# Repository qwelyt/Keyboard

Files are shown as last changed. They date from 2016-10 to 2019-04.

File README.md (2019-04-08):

# Keyboard
I'm building my own keyboard.
It's as simple as that.

Why? Because I want to. And I've yet to find a keyboard that looks the way I want it to. The solution seems to be to build your own. So that's what I'm doing.

## Layout
The layout is a split keyboard with the keys in a matrix. Here's a pic (v2)
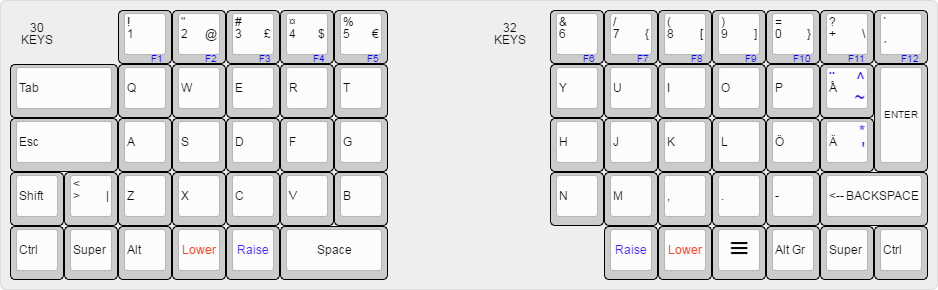
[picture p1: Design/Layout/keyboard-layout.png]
layout


### Why split?
Every keyboard I've tried have always forced you to put your hands inwards, in a / \ way (pretend that's your arms). But I want to be able to keep my arms like | | or even \ /. With a split keyboard where you can move each module to where you want it to be you can achive this. I *think* this would give you better ergonomics, but we'll see. We might be using the one-module-fits-all approach for more than just cheaper-to-produce reasons. But if you never try, you never know.

### Why a linear matrix layout?
As far as I've found, the only reason we use keyboards with slanted columns is because 'it has always been like that'. Like, from the typewriter-era. And then it was for mechanical reasons. But now that we no longer have metal arms that must be physically fit into the layout, we can design it just as we want. And apparently the slanted-columns-layout is bad for you. You stretch your fingers in an un-natural way which puts strain on your limbs and increases the odds of injury.
That is just bad. So I'm going for a linear matrix layout because I like my fingers. They should have the best typing experiance they can have.

### Raise and Lower?
Do you really use *F1* so much that it needs its own dedicated key? I don't. So tucking it away under *Raise*+*1* works well. I think. Also, doing it layered gives you way more keys than you actually have. Take module A. It has 30 keys. 2 of which are layer modifiers. This gives me 28 keys to play with, in three layers. So I actually got 28x3 keys, so thats 84 keys in total. I probably won't use that many, but it is nice to have the possibility. Mainly though, it cuts down on parts used and size, which is a big things given that 3D-printers (or at least mine) can't print super-mega-big things. 
Credit where it is due: The Planck keyboard has this (https://youtu.be/bEPg8kk84gw) which influenced me to have it as well.

## Parts
This build is my first keyboard that I'm building from scratch. I've done a few mods, but never a complete build.
To build this I'm using some mechanical switches (Black ALPS) that I 'rescued' from a to-be-thrown Dell AT101. I've got 104 keys from that old keyboard. Most of which still have the click sound. And I have the caps, ofc.

The modules cases is made to be 3D printed. I use a FlashForge Finder to print.

It's NKRO, so there is an 1N4149 diode for every switch.

The controller is an Arduino Micro (https://store.arduino.cc/arduino-micro).

Each module will be it's own keyboard. Meaning, each module will has it's own controller. So you don't need to plug in A to be able to use B and vice versa. This ofc means that, for 2 modules, you need 2 USB ports. One could build a USB hub as well to plug the modules into. Makes for a cleaner setup as you will only need 1 cable going to the computer. Might try building in retractable cables in everything if I take a stab at it, but well see how much of a pain that is.

# Log
| Todo | Doing | Done |
|---|---|---|
||| Create basic working matrix |
||| Create 3D sketches for modules |
|||Create schematics for matrix |
|||Get hands on a 3D printer|
||| Get diods |
||| Print test module |
||| Assemble test module |
||| Code test module |
||| Get real controller board |
||| Refactor |
||| Print module A |
||| Print module B |
||| Assemble A |
||| Assemble B |
||| Code A |
||| Code B |
|| ??? || 
| Refactor|||
| Profit|||

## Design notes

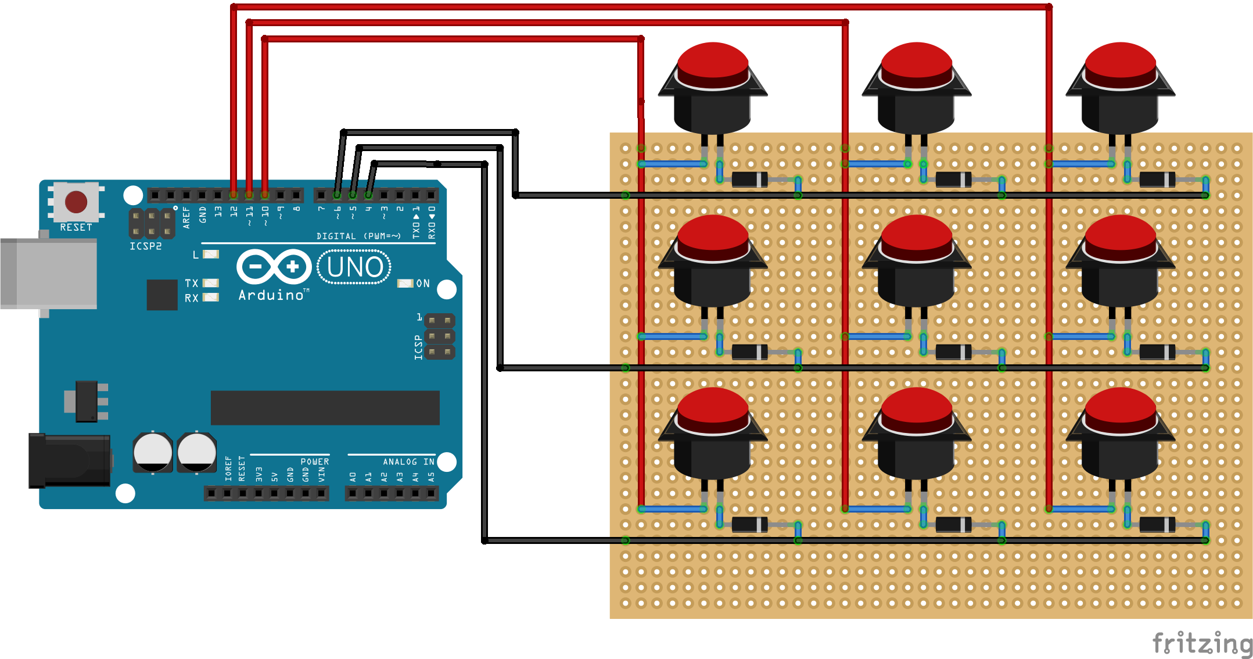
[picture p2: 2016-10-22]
Design/Schematics/matrix/matrix_bb.png

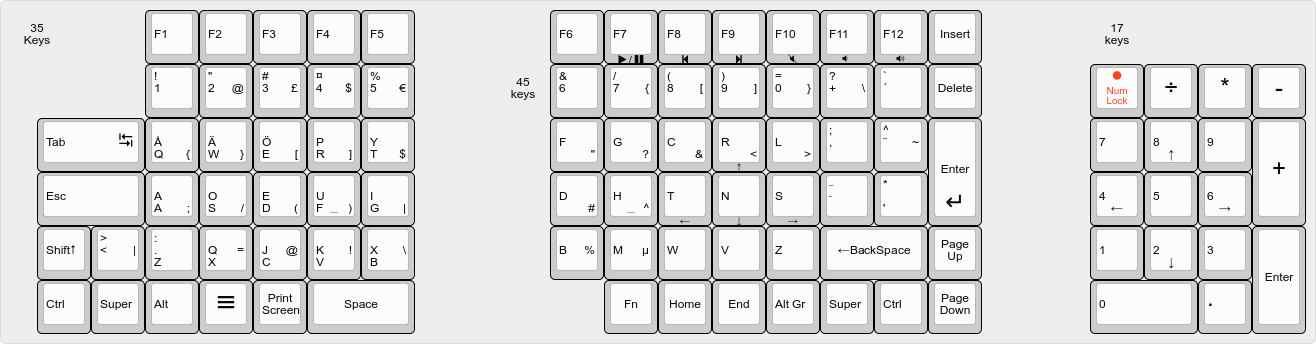
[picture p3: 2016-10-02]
Design/Layout/layout.png

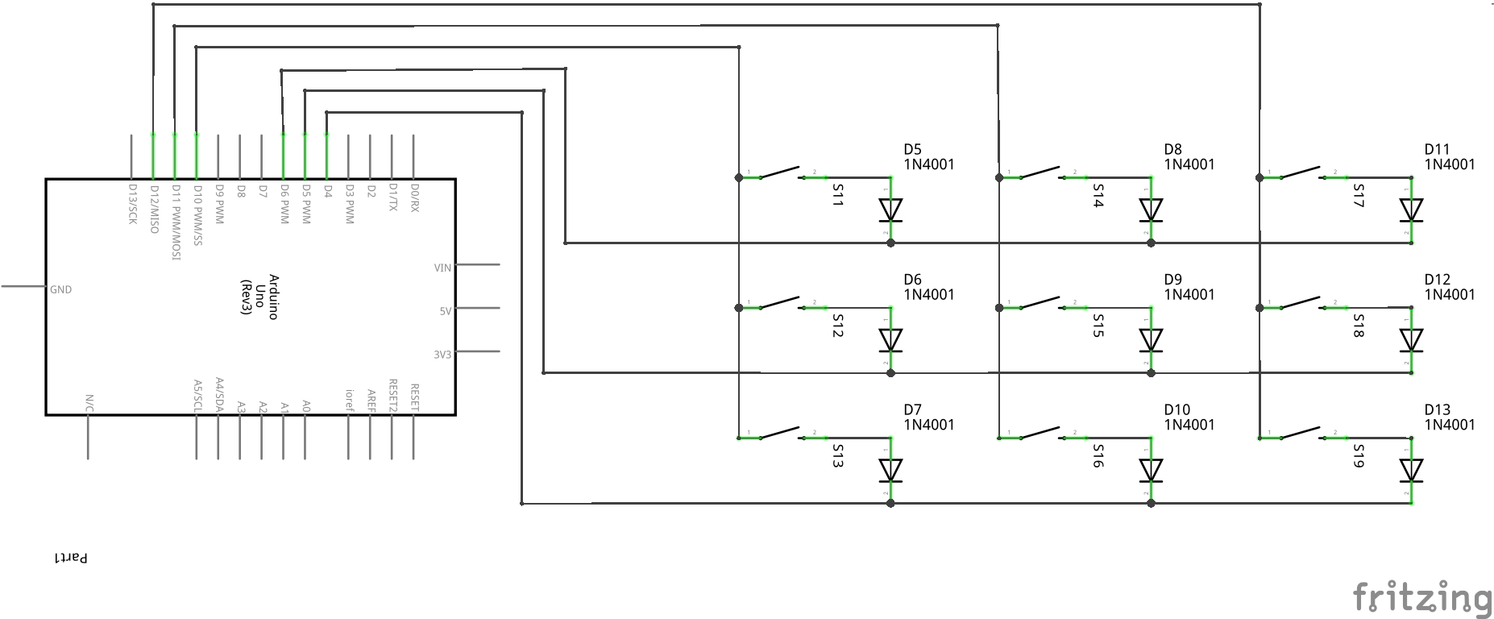
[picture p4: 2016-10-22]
Design/Schematics/matrix/matrix_schem.png

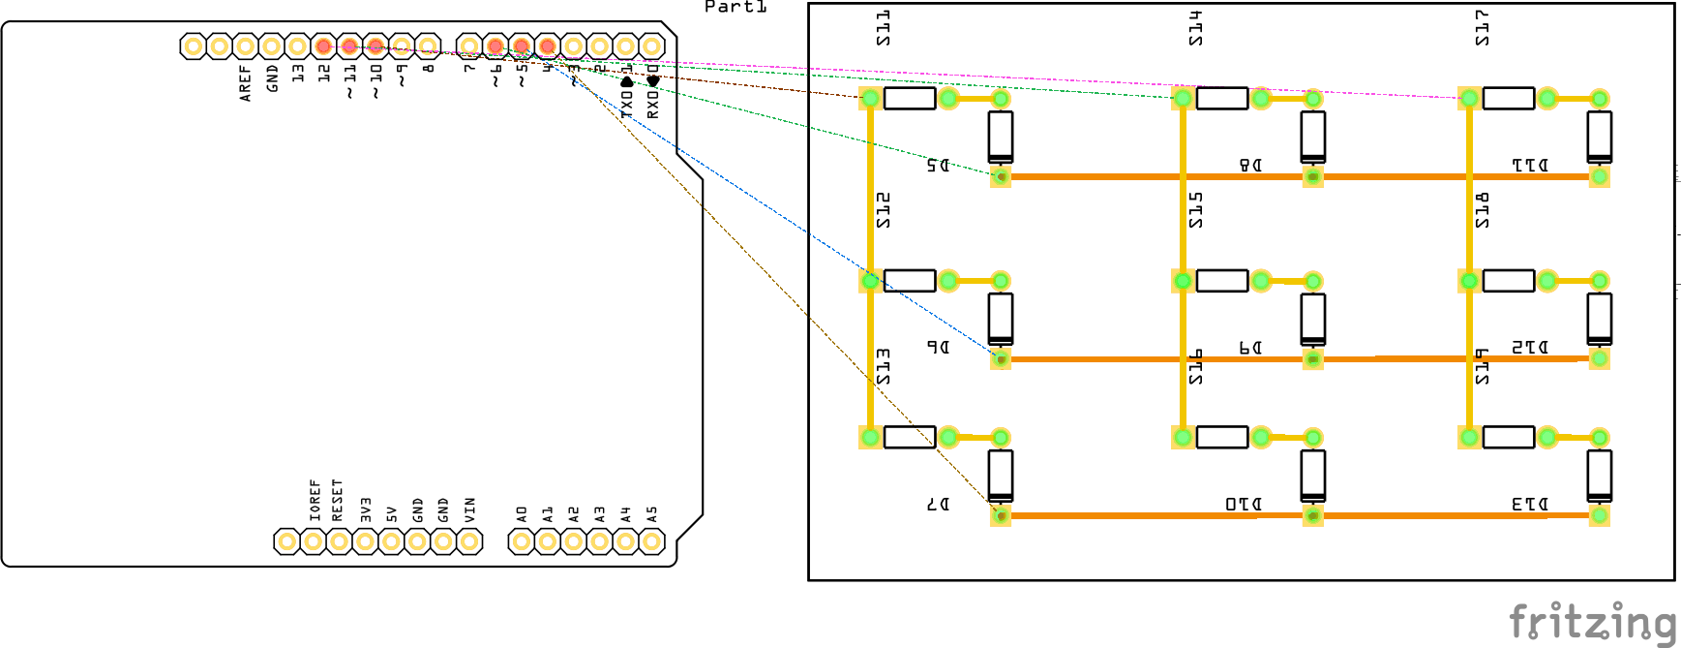
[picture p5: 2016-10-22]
Design/Schematics/matrix/matrix_pcb.png

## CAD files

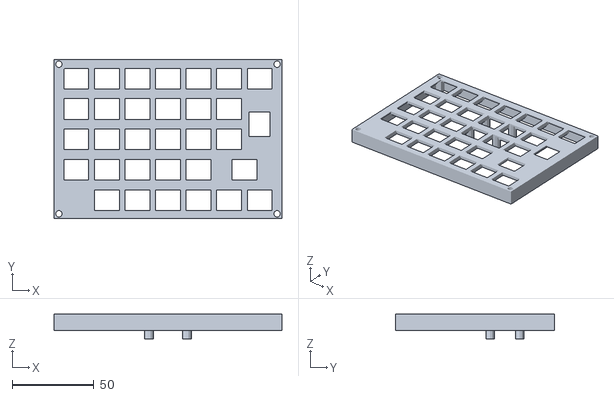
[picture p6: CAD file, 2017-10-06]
Design/SCAD/ModuleB/V2/moduleB_top_v2_Complete_top+spacer+uSupport.stl
139.4 x 97.5 x 15.0

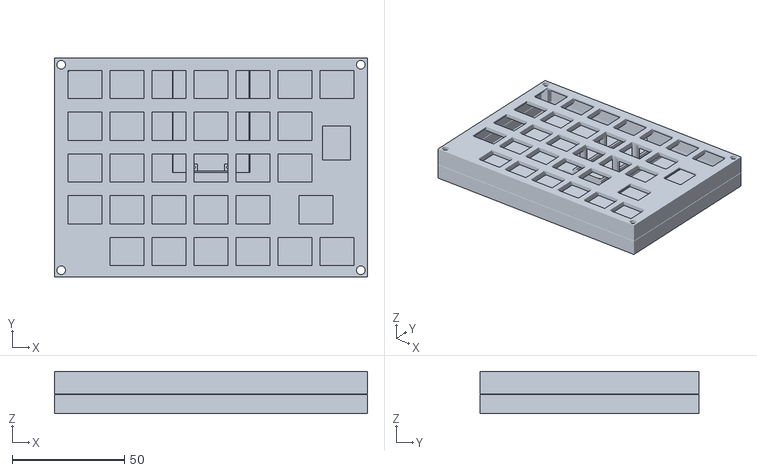
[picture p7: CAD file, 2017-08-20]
Design/SCAD/ModuleB/V2/moduleB_top_v2_Complete.stl
139.4 x 97.5 x 18.8

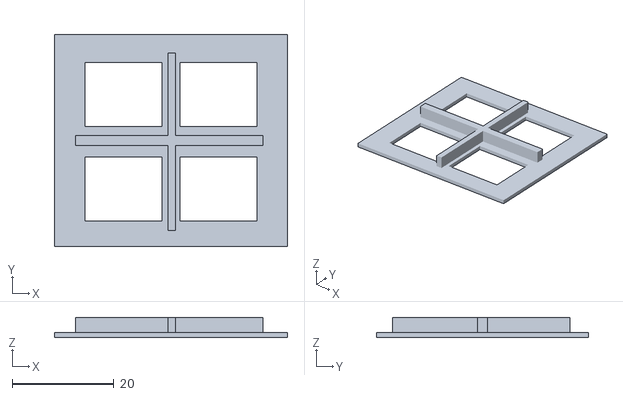
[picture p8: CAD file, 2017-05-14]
Design/SCAD/KeySizeTest/KeySize_15.2x12.6.stl
45.9 x 41.7 x 4.00

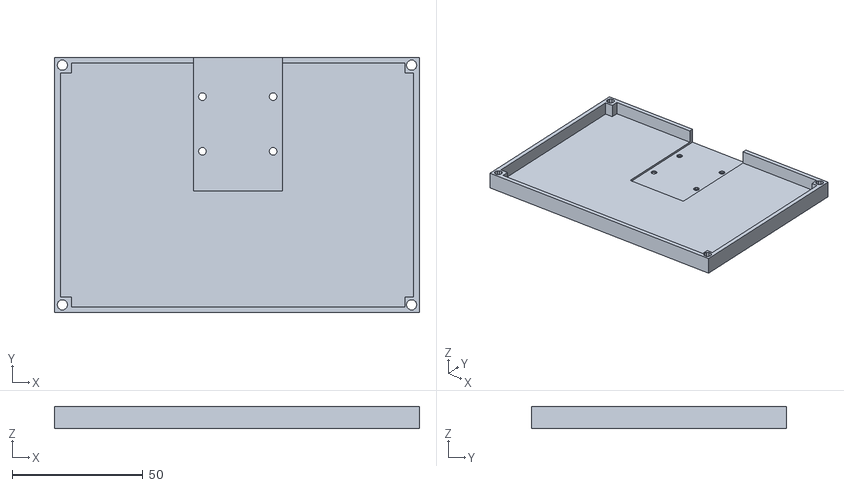
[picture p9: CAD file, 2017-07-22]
Design/SCAD/ModuleA/V2/moduleA_Bottom.stl
139.4 x 97.5 x 8.50

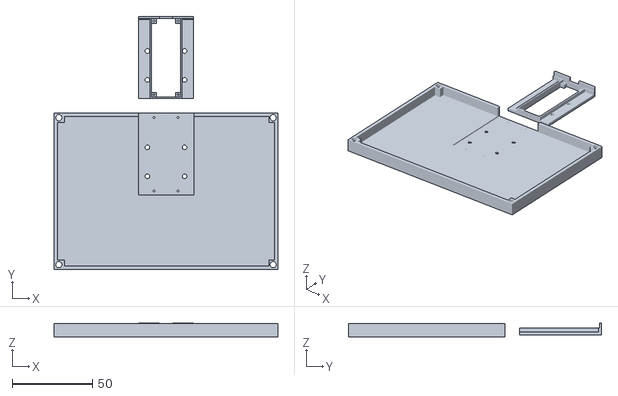
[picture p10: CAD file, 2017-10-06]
Design/SCAD/ModuleB/V2/moduleB_top_v2_holder+bottom.stl
139.4 x 157.5 x 8.60

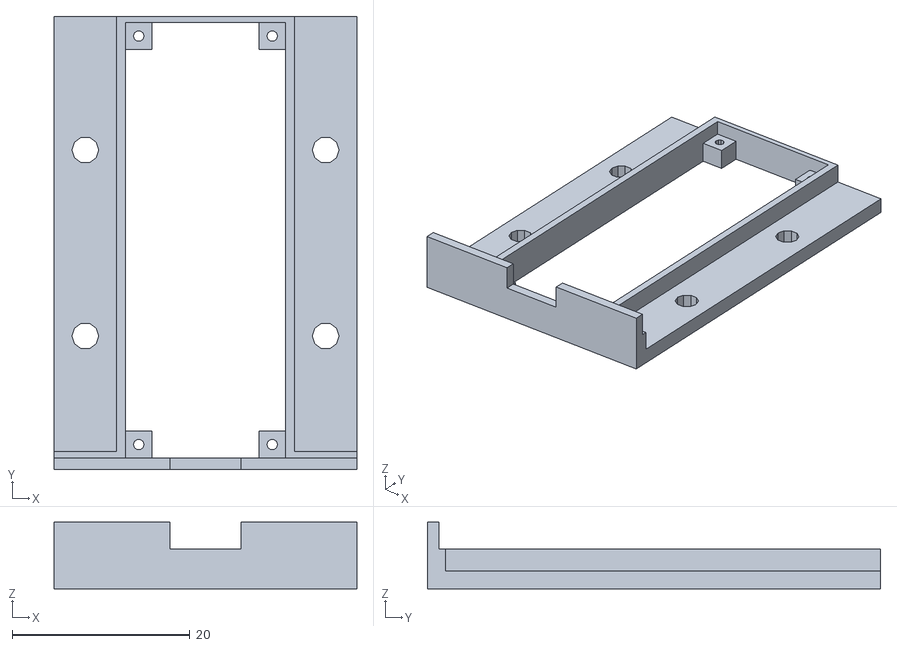
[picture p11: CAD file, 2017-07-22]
Design/SCAD/ModuleA/V2/moduleA_arudinoMicro_holder.stl
34.0 x 50.9 x 7.50

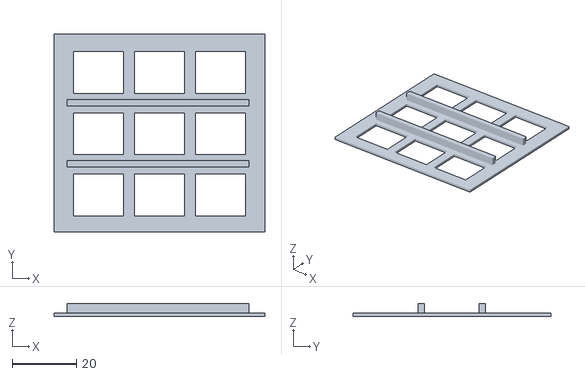
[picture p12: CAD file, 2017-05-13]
Design/SCAD/KeySizeTest/beams.stl
65.5 x 61.5 x 4.00

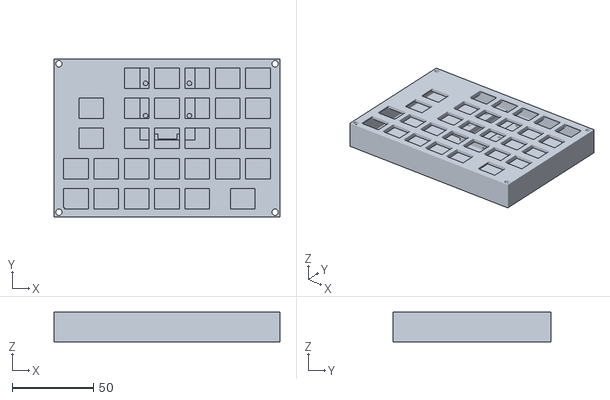
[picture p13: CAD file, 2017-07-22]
Design/SCAD/ModuleA/V2/mA.stl
139.4 x 97.5 x 18.5

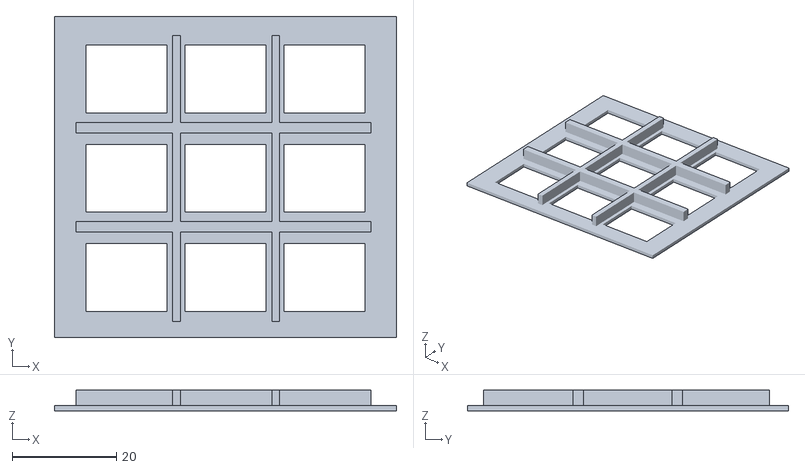
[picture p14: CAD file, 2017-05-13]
Design/SCAD/KeySizeTest/cross-beams.stl
65.5 x 61.5 x 4.00

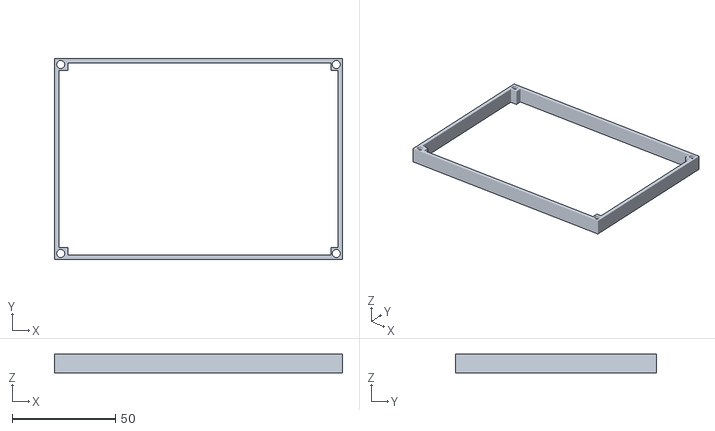
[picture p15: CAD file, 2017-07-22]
Design/SCAD/ModuleA/V2/ModuleA_Spacer.stl
139.4 x 97.5 x 9.00

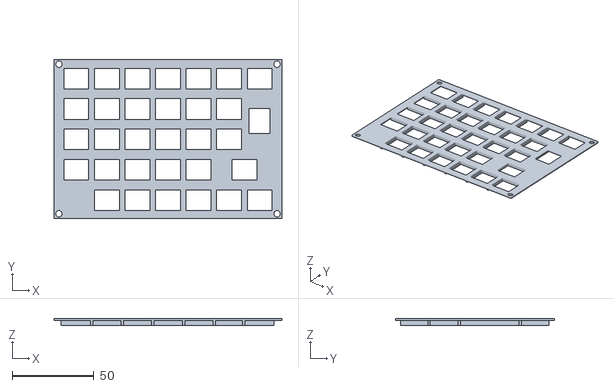
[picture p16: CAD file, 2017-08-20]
Design/SCAD/ModuleB/V2/moduleB_top_v2.stl
139.4 x 97.5 x 4.00

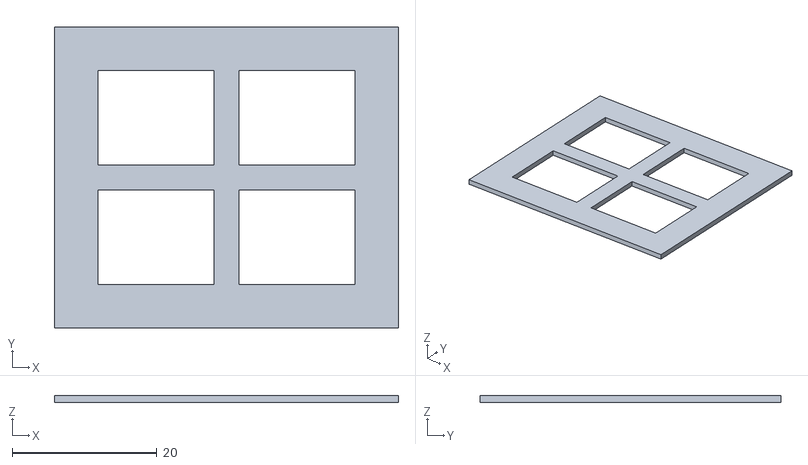
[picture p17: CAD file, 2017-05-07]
Design/SCAD/KeySizeTest/KeySize_16x13.stl
47.5 x 41.5 x 1.00

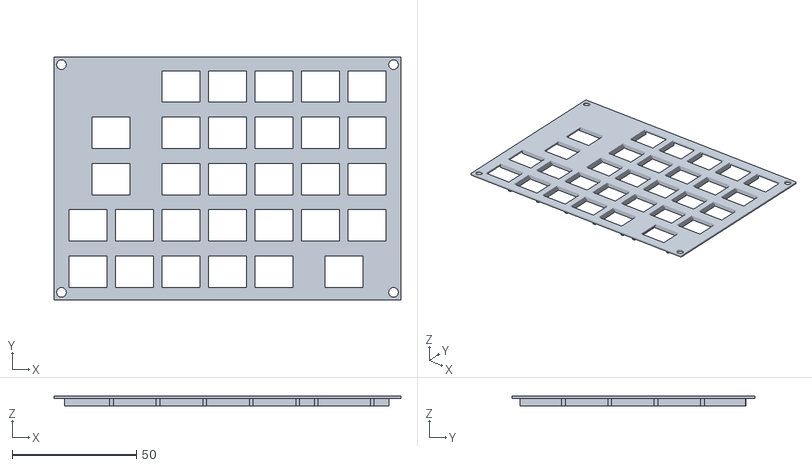
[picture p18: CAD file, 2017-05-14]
Design/SCAD/ModuleA/V2/moduleA_top_v2.stl
139.4 x 97.5 x 4.00

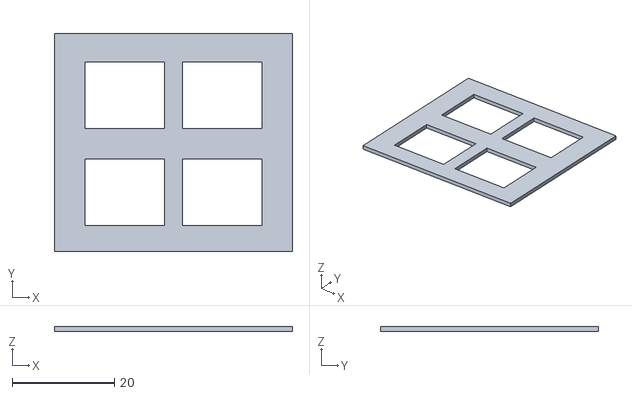
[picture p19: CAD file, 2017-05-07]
Design/SCAD/KeySizeTest/KeySize_15.5x13_moreSpace.stl
46.5 x 42.5 x 1.00

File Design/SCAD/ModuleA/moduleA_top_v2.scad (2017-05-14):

/* Module A v2
 * Fewer keys
 * Keycaps actually fit
 * Cross beams for support
 * Keys actally  fit, snuggly
 */
 
keyCols = 7;
keyRows = 5;
keyX = 15.2;
keyY = 12.6;
keySpace = 3.5;
vKeySpace=6;
edgeSpaceAddition = 4;
edgeSpace = (edgeSpaceAddition*2)-keySpace;
keyZ = -1;

supportH = 3.5;
supportW = 1.5;
supportZ = -3;

moduleX = (edgeSpace+edgeSpaceAddition)+(keySpace*keyCols)+keyX*(keyCols-1)+keyX;
moduleY = (edgeSpaceAddition*2-keySpace)+(vKeySpace*keyRows)+keyY*(keyRows-1)+keyY;
moduleZ = 1;

keySize = [keyX, keyY, moduleZ+2];

function position(x,y,z) = [edgeSpace+keySpace*x+keyX*(x-1)-(edgeSpaceAddition/2), edgeSpace-keySpace+(vKeySpace)*y+keyY*(y-1)-(edgeSpaceAddition/2), z];

module screwHole (x, y){
	translate([x,y,keyZ]) cylinder(h=moduleZ+2, r=2, $fn=10);
}

module keyHoles (yStart, yEnd, xStart, xEnd){
  for(y = [yStart:yEnd]){
    for(x = [xStart:xEnd]){
      translate(position(x,y,keyZ)) cube(keySize);
    }
  }
}

module hBeam (bStart, bEnd){
  for (b = [bStart:bEnd]){  
    color([0.5,0,0]){
      translate(position(0.9,b-0.2,supportZ)){  
        cube([moduleX-(edgeSpace*2),supportW,supportH]);
      }
    }
  }
}

module vBeam (bStart, bEnd){
  for (b = [bStart:bEnd]){  
    color([0.5,0,0]){
      translate(position(b-0.125,0.9,supportZ)){  
        cube([1.5,moduleY-(edgeSpace*1.5),supportH]);
      }
    }
  }
}

module vBeam2 (xStart, xEnd, yStart, yEnd){
  for (x = [xStart:xEnd]){  
      color([0.5,0,0]){
        translate(position(x-0.125,(0.9*yStart),supportZ)){  
          cube([1.5,(keyY*yEnd)-1.7,supportH]);
        }
      }
    }
}

difference(){
  cube([moduleX,moduleY,moduleZ]);
  keyHoles(1,1,1,5);
  keyHoles(1,1,6.5,6.5);
  
  keyHoles(2,2,1,7);
  
  keyHoles(3,3,1.5,1.5);
  keyHoles(3,3,3,7);
  
  keyHoles(4,4,1.5,1.5);
  keyHoles(4,4,3,7);
  
  keyHoles(5,5,3,7);
  
  screwHole(3,3);
  screwHole(3,moduleY-3);
	screwHole(moduleX-3,moduleY-3);
	screwHole(moduleX-3,3);
}

hBeam(2, keyRows);
//vBeam(2, keyCols);
vBeam2(6.4,6.4, 1, 1.5);
vBeam2(7.6,7.6, 1, 1.5);
vBeam2(2,2, 1, 3);
vBeam2(1.3,1.3, 3.2, 4.4);
vBeam2(2.6,2.6, 3.2, 4.4);
vBeam(3,6);
vBeam2(7,7, 2, 6);

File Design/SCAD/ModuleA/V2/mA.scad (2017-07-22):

color([1,0,0]){
  translate([0,0,8.5+9]) import("moduleA_top_v2.stl");
}


color([0,1,0]){
  translate([0,0,8.5]){ import("ModuleA_Spacer.stl");}
}

translate([(140-34)/2, 97.5-50, 1]){
color([0,0,1])translate([34,50,0])  rotate([0,0,180]) import("moduleA_arudinoMicro_holder.stl");

}

color ([1,1,0])translate([0,0,0]) import("moduleA_Bottom.stl");

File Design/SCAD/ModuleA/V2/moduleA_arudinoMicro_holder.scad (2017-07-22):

width= 34;
length = 51-0.1;
height = 4.5;

left = [40,0,0];
front = [-34,1,0];
under = [0,0,-10];
over = [0,0,10];

none = [0,0,0];

color([0,1,0]){
  translate(none){
    translate([0,0,0]){
      cube([13,1.3,7.5]);
    }
    translate([width-13,0,0]){
      cube([13,1.3,7.5]);
    }
      
    difference(){
      cube([width,length,height]);
      
      // Inner
      translate([8,1.3,2.65]){
        cube([18,length-2,3]); // Where arduino sits
      }
      
      smallHoles = 0.6;
      translate([11,1.3,0]){
        cube([12,length-2,3]); // remove middle short sides
        translate([-1.5,1.5,-1]) cylinder(h=20, r=smallHoles, $fn=10);
        translate([12+1.5,1.5,-1]) cylinder(h=20, r=smallHoles, $fn=10);
        
      }
      translate([8,4.3,0]){
        cube([18,length-8,3]); // remove middle longsides
        
        translate([1.5,length-8+1.5,-1]) cylinder(h=20, r=smallHoles, $fn=10);
        translate([18-1.5,length-8+1.5,-1]) cylinder(h=20, r=smallHoles, $fn=10);
      }
      
      // Outer
      translate([0,2,2]){
        cube([7,length,3]);
      }
      translate([27,2,2]){
        cube([7,length,3]);
      }
      
      //holes
      
      in  = 15;
      in2  = length-in;
      translate([3.5,in,0]){
        cylinder(h=20, r=1.5, $fn=10);
      }
      translate([width-3.5,in,0]){
        cylinder(h=20, r=1.5, $fn=10);
      }
      
      translate([3.5,in2,0]){
        cylinder(h=20, r=1.5, $fn=10);
      }
      translate([width-3.5,in2,0]){
        cylinder(h=20, r=1.5, $fn=10);
      }
      
      
    }
  }
}

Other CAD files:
Design/SCAD/KeySizeTest/KeySize_15.2x12.5.stl
Design/SCAD/KeySizeTest/KeySize_15x13.stl
Design/SCAD/KeySizeTest/KeySize_15.5x13.stl
Design/SCAD/ModuleA/V1/moduleA-top_smaller.stl
Design/SCAD/ModuleA/V2/moduleA_Bottom.scad
Design/SCAD/KeySizeTest/KeySize_15.2x12.5.scad
Design/SCAD/KeySizeTest/KeySize_15.2x12.6.scad
Design/SCAD/KeySizeTest/KeySize_15.5x13 .scad
Design/SCAD/KeySizeTest/KeySize_15.5x13_moreSpace .scad
Design/SCAD/KeySizeTest/KeySize_15x13 - Copy.scad
Design/SCAD/KeySizeTest/KeySize_16x13.scad
Design/SCAD/KeySizeTest/beams.scad
Design/SCAD/KeySizeTest/cross-beams - Copy.scad
Design/SCAD/ModuleA/V1/moduleA-backplate.scad
Design/SCAD/ModuleA/V1/moduleA-backplate.stl
Design/SCAD/ModuleA/V1/moduleA-build.scad
Design/SCAD/ModuleA/V1/moduleA-build.stl
Design/SCAD/ModuleA/V1/moduleA-middle.scad
Design/SCAD/ModuleA/V1/moduleA-middle.stl
Design/SCAD/ModuleA/V1/moduleA-top.scad
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

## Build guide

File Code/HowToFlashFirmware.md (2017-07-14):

# Flash the UNO using dfu-programmer
Short guide for how to flash the Arduino Uno using `dfu-programmer`

## Requriments
	* Arduino-keyboard-0.3.hex
	* Arduino-usbserial-uno.hex
	* dfu-programmer
	* dfu-util
	* Arduino Uno v3 (duh)

## Tell the Uno to enter 'flash-mode'
Create a connection between the pins closest to the USB-connection.
Right besid the USB-port there should be a reset-button. Near that button,
there should be 6 pins. The two pins in the front row are the pins you want
to create a connection between.

### Flash to keyboard
You will probably need root to execute the commands.
```
# dfu-programmer atmega16u2 erase
# dfu-programmer atmega16u2 flash --debug 1 Arduino-keyboard-0.3.hex
# dfu-programmer atmega16u2 reset
```
### Flash to normal UsbSerial
You will probably need root to execute the commands.
```
# dfu-programmer atmega16u2 erase
# dfu-programmer atmega16u2 flash --debug 1 Arduino-usbserial-uno.hex
# dfu-programmer atmega16u2 reset
```

## Check what firmware the Arduino currently has
```
% lsusb
```
If you see `Atmel Corp. LUFA Keyboard Demo Application`, the Uno has the keyboard-0.3.hex.  
If you see `Arduino SA Uno (CDC ACM)`, the Uno has the usbserial-uno.hex.  
If you see `Atmel Corp. atmega16u2 DFU bootloader`, the Uno is ready to be flashed with new firmware.

## After flashing
After you have flashed the Uno you need to power-cycle it for the new firmware to boot up.
You have to do this even if you haven't flashed it and just put in in 'flash-mode'.

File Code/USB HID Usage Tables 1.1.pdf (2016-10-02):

# HID Usage Tables

6/27/2001

### Version 1.11

### Please send comments via electronic mail to: hidcomments@usb.org

# Universal Serial Bus (USB)

1996-2001 USB Implementers’ Forum—All rights reserved.

ii | Universal Serial Bus HID Usage Tables
Version 1.11 | June 27, 2001

## Contributors

Brian M. Bates – ELO Touchsystems Robert Dezmelyk – LCS/Telegraphics Robert Ingman – Microsoft Corporation Rob Lieb – Symbol Technologies, Inc. Steve McGowan – Intel (Editor)
Kenneth Ray – Microsoft Corporation Steve Schumacher – LCS/Telegraphics Nathan C. Sherman - Microsoft Corporation Don Stern – TV Interactive
Mike Van Flandern – Microsoft Corporation Remy Zimmerman – Logitech International And many others.

Universal Serial Bus HID Usage Tables | iii

## Revision History

Revision | Issue Date | Comments
1.11 | June 27, 2001 | Version 1.11 release
1.11rc1 | August 7, 2000 | Incorporate HUT Review Request 1, 2, 3, 4, 5, 6, 7, 8, 9, 11, 13, 14, 15,16, 17, and 18.
1.1 | April 8, 1999 | Version 1.1 release
1.1rc3 | February 16, 1999 | Correct barcode Usage Page ID. Corrected page numbering.
1.1rc2 | January 21, 1999 | Incorporate HID Review Request 51.
1.1rc1 | October 13,1998 | Incorporate Keyboard Usage Table from the 1.0 HID Specification and HID Review Requests 16, 34, 38, 40, 41, 42, 43, 45, 46, 48 and 49.
1.0 | October 30, 1997 | Version 1

iv | Universal Serial Bus HID Usage Tables
| Copyright © 1996-2001, USB Implementers Forum All rights reserved.

INTELLECTUAL PROPERTY DISCLAIMER THIS SPECIFICATION IS PROVIDED “AS IS” WITH NO WARRANTIES WHATSOEVER INCLUDING ANY WARRANTY OF MERCHANTABILITY, FITNESS FOR ANY PARTICULAR PURPOSE, OR ANY WARRANTY OTHERWISE ARISING OUT OF ANY PROPOSAL, SPECIFICATION, OR SAMPLE.
A LICENSE IS HEREBY GRANTED TO REPRODUCE AND DISTRIBUTE THIS SPECIFICATION FOR INTERNAL USE ONLY. NO OTHER LICENSE, EXPRESS OR IMPLIED, BY ESTOPPEL OR OTHERWISE, TO ANY OTHER INTELLECTUAL PROPERTY RIGHTS IS GRANTED OR INTENDED HEREBY.
AUTHORS OF THIS SPECIFICATION DISCLAIM ALL LIABILITY, INCLUDING LIABILITY FOR INFRINGEMENT OF PROPRIETARY RIGHTS, RELATING TO IMPLEMENTATION OF INFORMATION IN THIS SPECIFICATION. AUTHORS OF THIS SPECIFICATION ALSO DO NOT WARRANT OR REPRESENT THAT SUCH IMPLEMENTATION(S) WILL NOT INFRINGE SUCH RIGHTS.
All product names are trademarks, registered trademarks, or service marks of their respective owners.

Please send comments via electronic mail to hidcomments@usb.org

Universal Serial Bus HID Usage Tables | v

## Table of Contents

vi Universal Serial Bus HID Usage Tables

Universal Serial Bus HID Usage Tables | vii

### 14.4 Speed Dial Controls | 73 14.5 Voice Mail Controls | 73 14.6 Locally Generated Tones | 73

### 15 CONSUMER PAGE (0X0C) | 75

### 15.1 Generic Consumer Control Device | 84 15.2 Numeric Key Pad | 85 15.3 General Controls | 85 15.4 Menu Controls | 85 15.5 Display Controls | 86 15.6 Selection Controls | 86 15.7 Transport Controls | 87 15.8 Search Controls | 88 15.9 Audio Controls | 89

15.9.1 Volume | 89
15.9.2 Balance | 89
15.9.3 Bass | 90
15.9.4 Treble | 90
15.9.5 Other | 90

### 15.10 Speed Controls | 90 15.11 Home and Security Controls | 91 15.12 Speaker Channels | 92

15.12.1 Audio Channels | 92

### 15.13 PC Theatre | 94 15.14 Programmable Buttons | 94 15.15 Application Launch Buttons | 94 15.16 Generic GUI Application Controls | 97

### 16 DIGITIZERS (0X0D) | 102

### 16.1 Digitizer Devices | 103 16.2 Digitizer Transducer Collection Usages | 104 16.3 Digitizer Report Field Usages | 104

16.3.1 Digitizer-Specific Fields | 104
16.3.2 Tilt Orientation | 105
16.3.3 Azimuth-Altitude Orientation | 105

### 16.4 Digitizer Switch Usages | 106

### 17 UNICODE PAGE (0X10) | 107

### 18 ALPHANUMERIC DISPLAY PAGE (0X14) | 108

### 18.1 Alphanumeric Display | 109

viii Universal Serial Bus HID Usage Tables

### 18.2 Flags | 109 18.3 Display Control | 112 18.4 Scrolling | 112 18.5 Character Transfers | 113 18.6 Display Status | 114 18.7 Cursor Control | 114 18.8 Font Loading | 116 18.9 Character Formats | 117

18.9.1 Matrix | 117
18.9.2 7-Segment | 117
18.9.3 14-Segment | 119

### 19 MEDICAL INSTRUMENT PAGE (0X40) | 120

### 19.1 Ultrasound Devices | 121 19.2 Acquisition Controls | 121 19.3 Signal Modulation | 122 19.4 Acquisition and Display Mode Controls | 122

APPENDIX A: USAGE EXAMPLES | 124
A.1 Volume Control | 124
A.1.1 Up/Down Buttons | 124
A.1.2 Knob | 124
A.2 Tape Jog Wheel | 124
A.3 Radio Buttons | 125
A.3.1 Mechanically Linked Radio Buttons | 125
A.3.2 Radio Buttons with No Mechanical Linkage | 125
A.4 Named Array Field | 125
A.5 Multiple Instances of a Control | 126
A.6 Multiple Instances of a Multi-Mode LED | 126
A.7 Desktop Tablet Example | 128
A.8 A Device with a Display | 131
A.9 Remote Control | 135
A.10 Telephone | 136
A.11.1 Multi-Line Snippet | 139
A.12 Joystick | 139
A.13 Game Pad | 141
A.14 Graphic Equalizer | 142
APPENDIX B: DELIMITER EXAMPLE | 145
APPENDIX C: PHYSICAL DESCRIPTOR EXAMPLE | 147

Universal Serial Bus HID Usage Tables | ix
USAGE INDEX | 151

x Universal Serial Bus HID Usage Tables

## List of Tables

Table 23: Graphic Equalizer Usage Descriptors (HID LANGID - 0x04FF) ... 143

Universal Serial Bus HID Usage Tables | xi

## List of Figures

Figure 1: String Descriptor | 23
Figure 2: LANGID Format | 24
Figure 3: GetDescriptor(String) Request | 24
Figure 4: Usage Data Descriptor | 25
Figure 5: Vendor Defined Descriptor | 26
Figure 6: System Power States | 32
Figure 7: Graphic Equalizer Data Descriptor | 85
Figure 8: Audio Channels | 92
Figure 9: 7-Segment Direct Mapping Data | 111
Figure 10: 14-Segment Direct Mapping Data | 111
Figure 11: Matrix Character Segment Mapping | 117
Figure 12: 7-Segment Character Segment Mapping | 118
Figure 13: 14-Segment Font Data | 119
Figure 14: 14-Segment Character Segment Mapping | 119
Figure 15: LED Report fields | 127
Figure 16: Example Digitizer 2-Button Stylus Input Report | 130
Figure 17: Example Digitizer 16-Button Puck Input Report | 130
Figure 18: Example Digitizer Pressure Stylus Input Report | 130
Figure 19: Example Display Attributes Feature Report | 133
Figure 20: Example Display Device Input Report | 133
Figure 21: Example Display Device Display Position Feature Report | 134
Figure 22: Example Display Device Character Feature Report | 134
Figure 23: Example Display Device Font Load Output Report | 134
Figure 24: Example Remote Control Input Report | 136
Figure 25: Example Telephony Device Input Report | 138
Figure 26: Example Telephony Device Output Report | 139
Figure 27: Example Joystick Input Device Report | 140
Figure 28: Example Game Pad Input Device Report | 141
Figure 29: Joystick Button Layout | 147

### 12 Universal Serial Bus HID Usage Tables

## 1 Introduction

Usages are part of the HID Report descriptor and supply an application developer with information about what a control is actually measuring or reporting. In addition, a Usage tag can be used to indicate the vendor’s suggested use for a specific control or group of controls. While most of the items within a Report descriptor describe the format of the data—for example, three 8-bit fields—the Usage tags define what should be done with the data—for example, x, y, and z input. This feature allows a vendor to ensure that the user sees consistent function assignments to controls across applications. It is also the key feature within HID Report descriptors that allows system or application software to know the meaning of data items, or collections of data items, so the data items can be correctly interpreted or routed to the system or application software that consumes them.

## 1.1 Scope

This document is the most current and complete list of currently defined usages. With the exception of the Keyboard/Keypad Page (0x07), this document is a superset of the usages defined in the USB Device Class Definition for Human Interface Devices (HID), also called the HID Specification. Keyboard/Keypad Page usages are listed in the HID Specification, and are not repeated in this document due to length. Usages for other pages listed in the HID Specification (Generic Desktop, LED, and Button pages) are repeated in this document with additional information. In case of a discrepancy, this document takes precedence over the HID Specification for those usages.
Usage definitions for Monitor, Power, Bar Code Scanner, and Point of Sale devices are in process as of this publication date and are not covered in this document. For details about those usages, see the device class specifications for those devices.

## 1.2 Purpose

This document defines constants that can be interpreted by an application to identify the purpose and meaning of a data field in a HID report.
Usages are also used to define the meaning of groups of related data items. This is accomplished by the hierarchical assignment of usage information to collections. Usages identify the purpose of a collection and the items it contains. Each Input, Output, Feature, and/or Collection data item within a Collection item can be assigned a purpose with its own usage item. Usages assigned to a collection apply to the items within the collection.
In some cases a usage applied to a collection can redefine the meaning of the usages it contains. An example of this is the Usage Selected Indicator on the LED page.
Usages are also used to specify the meaning of each element within an Array data item.

Universal Serial Bus HID Usage Tables | 13

## 1.3 Related Documents

Universal Serial Bus Specification, 1.0 Version (also referred to as the USB Specification)
USB PC Legacy Compatibility Specification
Universal Serial Bus Device Class Definition for Human Interface Devices (HID) (also referred to as the HID Specification)
USB Device Class Definition for Monitor Devices
USB Device Class Definition for Power Devices
USB Device Class Definition for Bar Code Scanners
USB Device Class Definition for Point of Sale Devices
USB Device Class Definition for Physical Interface Devices
Unicode Standard, version 1.1
International Character Encoding Standard, ISO/IEC10646-1 UCS-2 Open Arcade Architecture Device Data Format Specification

## 1.4 Terms and Abbreviations

Application | A software program that consumes the data generated by the HID device Input
reports, or that controls the HID device through Feature or Output reports. Applications can be games or other programs used by end users or system software components.
Array field | The bit field created by an Input, Output, or Feature main item which is
declared as an Array. An array field contains the index of a usage, not the usage value.
Control | A control is used to operate or regulate a particular aspect of a device. In this
document a control refers broadly to the physical entity on the device that the usage identifies.
Field | The Input, Output, and Feature main items create a bit field in a report. The
Report Size determines the field’s width and the associated usage determines the field’s purpose. The offset of a field in a report is determined by the fields that are declared before it.
Pad | If a field is marked as a constant and there is no usage associated with it, the
field will be treated as pad bits and ignored by host software.
Note: Fields created by Main items that do not have usages attached to them might not be accessible by applications. Whether such access is possible depends on the implementation of the HID device driver.
Usage | Defines the purpose or meaning of an item.

### 14 Universal Serial Bus HID Usage Tables

## 2 Management Overview

This document provides lists of usages and their descriptions that significantly extend the list of usages provided in the HID Specification. A HID usage communicates the intended function or meaning of a particular control. Usages provide a description of the data items in a HID device’s Input, Output, and Feature reports. The existence of a defined usage does not guarantee that system or application software will recognize or utilize the data item. Although usages can be very powerful, there is a potential for misuse. The detail provided in this document will help minimize the misuse or misinterpretation of usages when they are applied by a device developer.
Usages have been organized into pages of related controls. Each usage has a usage ID, usage name and a detailed description. The usage names are mnemonics, not definitions. To avoid misleading interpretations based on the usage name, it is very important that a developer review a usage’s description in detail to ensure that it properly identifies the purpose of the control or device that the usage is attached to.
In theory, a usage can be attached to any type of HID control, variable, array, collection, and so forth. In reality, usages only make sense when they are attached to particular controls and used in certain ways. A relatively small set of usage types have been defined to help the application software developer better understand what to expect when a particular usage is found. Each usage has a usage type associated with it. The usage type identifies the item types, flag settings and bit fields organizations that are found with a particular usage.
Usages can also identify functional devices as a whole, thus providing an easy method for an application to identify devices that provide functions of interest. Such usages are found attached to application collections that are wrapped around all the items that describe a particular functional device, or a particular function in a complex device. Generally an application will query the HID driver for all application collection usages that it knows pertain to it. For example, a gaming device driver might look for Joystick and Game Pad usages, while a system mouse driver might look for Mouse, Digitizer Tablet and Touch Screen usages.
As a general rule, the usages selected by a device developer should be specific enough to dissuade inappropriate use by applications while remaining general enough to allow applications to take advantage of device features if they can. If uncertain, favor the more general usage to encourage broader application support for your device. An alternative is to use delimiters to define multiple usages associated with a single control or a device. For details, see Appendix B, “Delimiter Example.”
Some usage pages that are in the HID Specification are also found in this document. They are included here because either additional text has been provided to clarify how the usages are to be used , new usages have been added to the page, or both. No changes have been made to the usage values assigned in the HID Specification.

Universal Serial Bus HID Usage Tables | 15

## 3 Usage Pages

The following table lists the currently defined usage pages and the section in this document or the specification where each page is described.

Table 1: Usage Page Summary

Page ID | Page Name | Section or Document
00 | Undefined
01 | Generic Desktop Controls | 4
02 | Simulation Controls | 5
03 | VR Controls | 0
04 | Sport Controls | 7
05 | Game Controls | 8
06 | Generic Device Controls | 9
07 | Keyboard/Keypad | 10
08 | LEDs | 11
09 | Button | 12
0A | Ordinal | 13
0B | Telephony | 14
0C | Consumer | 15
0D | Digitizer | 16
0E | Reserved
0F | PID Page | USB Physical Interface Device definitions for force feedback and related devices.
10 | Unicode | 17
11-13 | Reserved
14 | Alphanumeric Display | 18
15-3f | Reserved
40 | Medical Instruments | 19
41-7F | Reserved
80-83 | Monitor pages | USB Device Class Definition for Monitor Devices
84-87 | Power pages | USB Device Class Definition for Power Devices
88-8B | Reserved
8C | Bar Code Scanner page | USB Device Class Definition for Point of Sale Devices
8D | Scale page
8E | Magnetic Stripe Reading (MSR) Devices
8F | Reserved Point of Sale pages
90 | Camera Control Page | USB Device Class Definition for Image Class Devices

### 16 Universal Serial Bus HID Usage Tables

Page ID | Page Name | Section or Document
91 | Arcade Page | OAAF Definitions for arcade and coinop related Devices
92-FEFF | Reserved
FF00-FFFF | Vendor-defined

A bold usage definition in the following sections identifies a collection. Non-bold definitions are specific features related to a device that would be applied to individual controls that generate data. In many cases, specific usages can be used by a number of device types.

## 3.1 HID Usage Table Conventions

Usage ID 0 should always be reserved.
Usage ID 1 through 0x1F are reserved for “top level” collections. These usage IDs are not necessarily application-level but are used to identify general device types.
Usage page values are limited to 16 bits.
Usage ID values are limited to 16 bits.
Usages are 32-bit identifiers, where the high order 16 bits represents the usage page and the low order 16 bits represents the usage ID. To allow more compact Report descriptors, Usage Page items can be declared to specify the high order bits of the Usage item and the Usage items can declare only the ID portion of the usage, as follows:
- If the bSize field of the Usage item equals 1 or 2, the entire 1- or 2-byte data portion of the item is interpreted as a usage ID.
- If the bSize field equals 3, bits 16-31 of the 4-byte data portion of the item are interpreted as a usage page, and bits 0-15 of the data portion are interpreted as a usage ID. This interpretation of usages applies to Usage, Usage Minimum, and Usage Maximum items.
The notation for a 32-bit usage (sometimes called an extended usage) in the examples is
Usage(Usage Page: Usage ID).

## 3.2 Handling Unknown Usages

If a usage is unknown to an application then the application should ignore it.
If the usage attached to a collection is unknown to an application, then the application should ignore the collection and all usages contained in the collection. A collection can be used to modify the meaning of the usages that it contains, therefore “known” usages within an unknown collection may not represent their original meaning. An example of this is the Usage Selected Indicator on the LED page.
System software provides capabilities for parsing HID Report descriptors. In some cases the usage associated with the top level application collection can be used by the system software as a key to load an application-specific driver or a mapping driver for legacy compatibility.

Universal Serial Bus HID Usage Tables | 17

## 3.3 Usages and Units

For usages that declare data items as a measurement of time, distance, force, and so forth, an application must look at the units to properly interpret the value defined by a usage, unless:
1. The usage specifically declares Units as optional.
2. The usage description defines the units in which the value will be presented.
If Units are set to Optional or set to None (have not been declared) then an application can assume the usage represents a dimensionless value. Any application that ignores Units does so at its own risk.
A usage that declares itself to be a measurement of time would specify whether it was seconds or milliseconds by declaring Units and Unit Exponent prior to the respective Main item declaration. An example of this is the Flash On Time usage on the LED page, which is described as the duration that the indicator is illuminated in flash mode. The duration would be qualified by the values of Units and Unit Exponent.
When declaring Units for a main item, the Logical Minimum, Logical Maximum, Physical Minimum, Physical Maximum, and Unit Exponent items must also be declared.

In many cases the coordinate system assumes that the values can vary both positively and negatively from zero (0).

## 3.4 Usage Types

Usages define a wide variety of device features. However, the way an application treats the data that they generate falls into a relatively small set of categories. This section provides descriptions of frequently used types of usages, primarily to save redundant text throughout this document. This list is not an exhaustive list of the possible usage types. Individual usage pages can declare their own usage types.
Each usage type describes how an application should treat the data generated by the Main item that the usage is attached to.
Usage type names are followed by an abbreviation that is used in the detailed usage description to identify the default type of a usage. In some cases usage types do not apply and the detailed description will identify how the usage is to be interpreted.
There are three basic types of information that are described by usages: controls, collections, and data. In this context, controls are identified with the state of a device (on/off, enable/disable, and so forth), collections group related controls and data together, and data comprises the remaining information that is passed between a device and the host.

Usage types are always considered to be the recommended method of handling a usage. Consult the usage’s definition to determine whether alternative usage types may apply.

Note

Note

### 18 Universal Serial Bus HID Usage Tables

### 3.4.1 Usage Types (Controls)

The following table summarizes the control related usage types.

Table 2: Usage Types (Controls)

Control Type | Logical Min | Logical Max | Flags | Signal | Operation
Linear Control (LC) | –1 | 1 | Relative, Preferred State | Edge | 1 increments the control’s value. –1 decrements the control’s value.
| –Min | Max | Relative, Preferred State | Level | n increments the control’s value. –n decrements the control’s value.
| Min | Max | Absolute, Preferred State | N/A | The value reported by the control is used directly by the host.
On/Off Control (OOC) | -1 | 1 | Relative, No Preferred | Edge | 1 asserts an On condition. –1 asserts an Off condition.
| 0 | 1 | Relative, Preferred State | Edge | A 0 to 1 transition toggles the current On/Off state.
| 0 | 1 | Absolute, No Preferred | Level | 1 asserts an On condition. 0 asserts an Off condition.
Momentary Control (MC) | 0 | 1 | Absolute, Preferred State | Level | 1 asserts a condition. 0 deasserts the condition.
One Shot Control (OSC) | 0 | 1 | Relative, Preferred State | Edge | A 0 to 1 transition triggers an event. A 1 to 0 transition must occur before another event can be triggered.
Re-trigger Control (RTC) | 0 | 1 | Absolute, Preferred State | Level | 1 triggers an event. When an event completes, if the value is 1 then the event will be triggered again.

### 3.4.1.1 Linear Control (LC)

In many cases, a control of a linear value is implemented as a pair of increment/decrement buttons, a jog wheel, or a linear control such as a knob or a slide.
When implemented as an increment/decrement control, the two buttons must be translated into a single, 2-bit signed value and declared as a Relative Main item with a Report Size equal to 2, where –1 decrements the value, +1 increments it, and no change occurs when 0 is asserted.
A jog wheel is normally implemented as a spring-loaded knob that returns to a fixed center position when released. This control reports a single value of two or more bits which are reported as a signed value and declared as a Relative Main item where –n decrements the value, +n increments it, and no change occurs when 0 is asserted. A jog wheel control is implemented with a resolution of +/–n, where the offset of the knob from the center position is proportional to the reported value. The Report Size must be declared large enough to contain the signed value n.
When implemented as a linear knob or slide, the control must be declared as an Absolute Main item. For an example, see Section A.1, “Volume Control,” in Appendix A, “Usage Examples.”

Universal Serial Bus HID Usage Tables | 19

### 3.4.1.2 On/Off Control (OOC)

An On/Off Control can be implemented in any of the following ways:
- Two buttons, On and Off. The two buttons are encoded into a 2-bit signed value and declared as a Relative, No Preferred Main item with Logical Minimum and Logical Maximum of –1 and 1, respectively. The transition from 0 to –1 generates an Off condition and the transition from 0 to +1 generates an On condition. No change occurs when 0 is asserted.
- A single button that toggles the On/Off state each time it is pressed. (single throw momentary switch The single button is encoded into a 1-bit unsigned value and declared as an Relative, Preferred Main item with a Logical Minimum and Logical Maximum of 0 and 1, respectively. The transition from 0 to 1 toggles the current On/Off state. No change occurs on the 1 to 0 transition.
- A toggle switch that maintains the On/Off state mechanically. (toggle switch) This control is encoded into a 1-bit unsigned value and declared as an Absolute, No Preferred Main item with a Logical Minimum and Logical Maximum of 0 and 1, respectively. The assertion of 1 generates an On condition and the assertion of 0 generates an Off condition.

### 3.4.1.3 Momentary Control (MC)

A Momentary Control is a basic push button. A Momentary Control is encoded into a 1-bit value and declared as an Absolute, Preferred Main item with a Logical Minimum and Logical Maximum of 0 and 1, respectively. A value of 1 generates an asserted condition and 0 generates a non-asserted condition. An example is a mouse button.

### 3.4.1.4 One Shot Control (OSC)

A One Shot Control is a push button that triggers a single event or action. A One Shot Control is encoded into a 1-bit value and declared as a Relative, Preferred Main item with a Logical Minimum and Logical Maximum of 0 and 1, respectively. A 0 to 1 transition initiates an event. Nothing occurs on a 1 to 0 transition but it is required before another event can occur. An example is degauss.

### 3.4.1.5 Re-Trigger Control (RTC)

A Re-Trigger Control is a push button that triggers a repeating event as long as it is asserted. A Re-Trigger Control is encoded into a 1-bit value and declared as an Absolute, Preferred Main item with a Logical Minimum and Logical Maximum of 0 and 1, respectively. A 0 to 1 transition initiates the first event. When each event terminates, if the control is still asserted (1) then another event will occur. An example is an auto-repeat fire button.

### 3.4.2 Usage Types (Data)

The following table summarizes the data-related usage types.

Table 3: Usage Types (Data)

Type | Flags | Description
Selector (Sel) | Array | Contained in a Named Array (NAry).
Static Value (SV) | Constant, Variable, Absolute | A read-only multiple-bit value.
Static Flag (SF) | Constant, Variable, Absolute | A read-only single-bit value.
Dynamic Value (DV) | Data, Variable, Absolute | A read/write multiple-bit value.
Dynamic Flag (DF) | Data, Variable, Absolute | A read/write single-bit value.

### 20 Universal Serial Bus HID Usage Tables

### 3.4.2.1 Selector (Sel)

Selectors come in three forms:
- One selection of a set. Radio buttons are a mechanically linked set of buttons where one selection is always valid. This is a perfect example of the “one selection of a set” form. A radio button set is defined by a Main item with the Array flag set and the Report Count set to 1. The index returned in the array field corresponds to the pressed button (or selection). A usage must be declared for each selection. The array field never returns an index of NULL because one usage is always valid. An example is Stat Not Ready on the Alphanumeric Display page.
- N selections of a set. More than one selection (button) can be valid at a time. Multiple selections can be returned to the system at one time in a multi-byte array. The “n selections of a set” form is defined by a Main item with the Array flag set and the Report Count set to n, where n is the number of selections that can be reported in a single report. An example is a keyboard.
- Any selection of a set. The control is implemented as a set of bit fields in which each bit represents a single selection. This control is defined by a Main item with the Variable flag set and the Report Size equal to 1. The Report Count will be equal to the number of selections in the set.
Selectors therefore can be implemented in a number of ways: Array[1] (one selection of a set), Array[n] (n selections of a set), or bitmap (any selection of a set).
Optionally, the array field or set can be named by wrapping a set of Selectors in a logical collection with a usage attached to it. For details, see Section 3.4.3.1, “Named Array (NAry).”

### 3.4.2.2 Static Value (SV)

Static values are used to declare a fixed features in a device. They are defined as Constant and treated as read-only information. Therefore, asserting this field in a Set_Report command has no defined effect.

### 3.4.2.3 Static Flag (SF)

Static flags are used to declare the existence of a fixed feature in a device. If a Static Flag usage is found in a Report descriptor then the field must be read to determine whether the feature identified by the flag exists. A value of 1 indicates existence and a value of 0 indicates non-existence. The absence of a Static Flag usage implies that the flag is false or the feature defined by the flag is not supported by the device. A Static Flag must be declared as a Constant. To be accessible by applications, a Static Flag must have a usage assigned to it.
Static Flags are typically declared in a Feature report as a single-bit field where the value is always read as
1. Attempting to modify this field in a Set_Report command has no effect on a Static Flag.

### 3.4.2.4 Dynamic Flag (DF)

Dynamic Flags are used to declare the existence of a host-controllable feature in a device. The absence of a Dynamic Flag usage implies that the flag is false or the feature defined by the flag is not supported by the device.
Dynamic Flags are typically declared in a report as a single-bit field, where a value of 1 returned by the device indicates that the feature is enabled. The assertion of 1 by the host will cause the feature to be evoked and the assertion of 0 indicates that the feature is to be disabled or ignored if the feature is a one-time event (such as Degauss or Clear Display). A Dynamic Flag Main item must be declared as Data.

Universal Serial Bus HID Usage Tables | 21

### 3.4.2.5 Dynamic Value (DV)

A Dynamic Value is an n-bit field that contains a value associated with a control. The associated Main item will have the Data and Variable flags set. A Dynamic Value Main item must be declared as Data.

More advanced devices may allow a usage declared as a Static type to be Dynamic. Always check the Constant/Data flag in an Input, Output or Feature Main item.

### 3.4.3 Usage Types (Collection)

The following table summarizes the collection-related usage types.

Table 4: Usage Types (Collection)

Type | Collection Type | Definition
Named Array (NAry) | Logical | A collection that encompasses an array definition, naming the array set or the field created by the array.
Application Collection (CA) | Application | Applies a name to a top level collection which the operating system uses to identify a device and possibly remap to a legacy API.
Logical Collection (CL) | Logical | A logical collection of items.
Physical Collection (CP) | Physical | A physical collection of items.
Usage Switch (US) | Logical | Modifies the purpose or function of the usages (controls) that it contains.
Usage Modifier (UM) | Logical | Modifies the purpose or function of the usages (controls) that contains it.

### 3.4.3.1 Named Array (NAry)

To simplify for an application the process of finding a set of selectors, whether defined as an Array Field or a bitmap, the set of selectors can be named by wrapping them in a logical collection and applying a usage to the collection. Usages applied in this way are called Named Array usages. For an example, see Section A.4, “Named Array Field,” in Appendix A, “Usage Examples.”

### 3.4.3.2 Collection Application (CA)

The Collection Application usage type identifies usages that are used only in application-level collections. An application collection identifies a HID device or a functional subset of a complex device. An operating system uses the usage associated with this collection to link the device to its controlling application or driver. Common examples are a keyboard or mouse. A keyboard with an integrated pointing device could contain two different application collections.

Data reports cannot span application collections.

### 3.4.3.3 Collection Logical (CL)

The Collection Logical usage type identifies a usage applied to a logical collection. Logical collections can be used to further define the purpose of the items or controls that they contain.

Note

Note

### 22 Universal Serial Bus HID Usage Tables

### 3.4.3.4 Collection Physical (CP)

The Collection Physical usage type identifies a usage applied to a physical collection, usually a collection of axes. A physical collection is used for a set of data items that represent data points collected at one geometric point. This is useful for sensing devices that may need to associate sets of measured or sensed data with a single point. It does not indicate that a set of data values comes from one device, such as a keyboard. In the case of a device that reports the position of multiple sensors, physical collections are used to show which data comes from which sensor.

### 3.4.3.5 Usage Switch (US)

The Usage Switch usage type identifies a usage applied to a logical collection that modifies the purpose of the usages in that collection. An example is indicators. To avoid having to define a usage for every control that could possibly use an indicator (for example, Play/Play Indicator, etc.) a Usage Switch collection can be wrapped around a usage (Play) to create a indicator for the same function. Usage Switches often modify the type of the contained usage as well.

### 3.4.3.6 Usage Modifier (UM)

The Usage Modifier usage type identifies a usage applied to a logical collection. This logical collection is always contained in another logical collection. The purpose and possibly the type of the usage attached to the encompassing collection is modified. For instance the usage attached to the encompassing collection may not normally be defined as a collection. For an example, see Section A.6, “Multiple Instances of a Multi-Mode LED,” in Appendix A, “Usage Examples.”

### 3.4.4 Alternate Types

Usage types are a guide, not the rule. The flags, Logical Minimum and Logical Maximum values, and other Main item attributes must be evaluated by applications and system software to determine the true purpose, meaning, or interpretation of a control.
In many cases, a usage can take on the attributes of a usage type other than its default type. The alternate type can be declared by a collection in which the usage is found or implied by the way it is declared in a Report descriptor. For example, Usage In Use Indicator from the LED page is an example of an alternate usage type being applied to a usage. When a usage is wrapped in a Usage In Use Indicator collection, it becomes an On/Off Control (OOC).
In other cases, a usage can be declared as either a Static Value (SV) or a Dynamic Value (DV). For example, in a screen saver, the Screen Saver Delay might be fixed on one device and variable on another. The same thing can happen with usages declared as Static Flag (SF) or Dynamic Flag (DF).
Another example is a usage that is declared as either an On/Off Control (OOC) or a Selector (Sel). A device that can support a variety of operational modes will declare individual bits as On/Off Controls to identify which modes are enabled. However, when the device is running, only one mode will be in effect at a time. The device would then declare the same usage as a Selector and report this in a Named Array field to identify the mode associated with the current data. For example, a tape transport could have three states: Stopped, Paused, and Playing. This could be implemented as three individual bits where only one bit is true at a time, or as a 2-bit field in which 0 = Stopped, 1 = Paused, and 3 = Playing.

Universal Serial Bus HID Usage Tables | 23

## 3.5 System Controls

Applications look at the usage applied to top-level application collections to identify devices. System software that supports keyboards, mice, and joysticks follow the same conventions. If a device vendor wants a device to be recognized by the system software as one of these devices, then the device must follow the conventions described in this section.

### 3.5.1 Keyboard

Typical system software will search for application collections tagged with either a Keyboard or a Keypad usage. When found, the usages contained in these collections will be treated as standard system keyboard input. All devices that use these declarations will have their output routed to the same destination. That is, typing on any device will affect the active application.

### 3.5.2 Mice

Typical system software will search for application collections tagged with either a Mouse or a Pointer usage. When found, the usages generated by these collections will be treated as standard system pointer input. All devices that use these declarations will have their output routed to the same destination. That is, moving any mouse will affect the system pointer.

### 3.5.3 Joysticks

Typical system software will search for application collections tagged with either a Joystick or a Game Pad usage. When found, the usages generated by these collections will be treated as standard system joystick (gaming device) input. Devices that use these declarations will have their output routed to separate destinations, allowing multiple-player applications.

## 3.6 HID LANGIDs

This section identifies a set of conventions that allow static data to be associated with individual controls. These conventions are an extension of the string descriptors that can currently be attached to controls.
The first two bytes of a USB string descriptor define the length and type of the descriptor, respectively. The byte wide length field allows a "string" to be up to 253 bytes long. The second byte of a string is always the "String" descriptor type (0x03). These bytes are followed by 16-bit UNICODE characters.

Figure 1: String Descriptor

Part | Offset/Size (Bytes) | Description | Sample Value
bLength | 0/1 | Size of this descriptor in bytes. | 0x06
bDescriptorType | 1/1 | String (assigned by USB). | 0x03
bString | 2/bLength-2 | UNICODE encoded string | 0x0041, 0x0042 = ("AB")

Strings on a HID device are accessed using a Language ID (LANGID) and a string index. The LANGID is a 16-bit value where the low order 10 bits are "Primary Language ID" and the high order 6 bits are the "Sublanguage ID". The Primary Language ID 0xFF has been permanently assigned to the HID class for it's use. The Sublanguage IDs are defined in Table 5. The String Index, String Minimum and String Maximum local items allow string indices to be associated with individual main items.

### 24 Universal Serial Bus HID Usage Tables

Figure 2: LANGID Format

15 | 14 | 13 | 12 | 11 | 10 | 9 | 8 | 7 | 6 | 5 | 4 | 3 | 2 | 1 | 0
Sublanguage ID Assigned by HID | | | | | | Primary Language ID 0x0FF (HID)

Individual usages define which HID LANGIDs they support and any support information the LANGID may require.

### Remarks:

- If a device declares LANGID's other than HID LANGID then return an empty string if there is no valid Unicode representation for it.
- All values are transmitted with little-endian byte alignment and in packed structures unless otherwise stated in the Usage description.
HID LANGIDs define how their associated string data is to be interpreted.
String descriptors are global to a device and assumed to be static, therefore cacheable. If a device requires that the Private Data varies as a function Configuration or Interface settings then a device must use non-overlapping indices to ensure that string caches do not need to be invalidated,
To implement HID LANGIDs the following steps are required:
1) String index 0 always defines a list of the LANGIDs supported by the HID device. A HID LANGID must be included in the list.
2) Any main item that utilizes HID LANGIDs must have a string index attached to it, using String Index, String Minimum or String Maximum local items.
3) A "string" must be returned by the device, which contains the data identified by the LANGID.
To access a HID LANGID string associated with a control, the host will send a GetDescriptor(STRING_DESCRIPTOR, HID_LANGID, String Index) request to the device, where STRING_DESCRIPTOR = 0x03, the HID_LANGID is defined in table ??, and the String Index is defined the String local item associated with the control.
Figure 3: GetDescriptor(String) Request
Part | Offset/Size (Bytes) | Description | Sample Value
bmRequestType | 0/1 | Device to Host, Standard, Device | 10000000B
bRequest | 1/1 | GET_DESCRIPTOR | 0x06
WValue (High) | 2/1 | STRING_DESCRIPTOR | 0x03
WValue (Low) | 3/1 | String Index
wIndex | 4/2 | HID(Usage Defined)
wLength | 6/2 | Length of string

See the Consumer Control:Equalizer Gain usage for an example that employs a HID LANGID.

Universal Serial Bus HID Usage Tables | 25

Table 5: HID Sublanguage IDs
Sublanguage ID | LANGID Name | Description
0x00 | | Reserved
0x01 | Usage Data Descriptor | Allows a usage to define a data structure that is specific to the usage.
0x02 - 0x3B | | Reserved
0x3C | Vendor Defined HID LANGID 1
0x3D | Vendor Defined HID LANGID 2
0x3E | Vendor Defined HID LANGID 3
0x3F | Vendor Defined HID LANGID 4

### 3.6.1 Usage Data Descriptor (0x01)

This HID LANGID allows a usage to define a private descriptors. A usage that requires private data must define the format of the block of data associated with the usage. The first two bytes of the table are identical to those defined in a standard USB string descriptor: bLength and bDescriptorType. The size and number of remaining fields depends on the Usage.

Figure 4: Usage Data Descriptor

Part | Offset/Size (Bytes) | Value | Description
bLength | 0/1 | Number | Size of this descriptor in bytes
bDescriptorType | 1/1 | Constant | String (assigned by USB)
Field 1 | 2/Field 1 size | Usage Dependent | Usage defined fields
Field 2 | Field 1 offset + Field 1 size /Field 2 size | Usage Dependent
Field 3 | Field 2 offset + Field 2 size /Field 3 size | Usage Dependent
… | … | Usage Dependent
Field n | Field n-1 offset + Field n-1 size /Field n size | Usage Dependent

### 3.6.2 Vendor Defined HID LANGID (0x3C - 0x3F)

Four HID LANGIDs are reserved for vendor specific use. The first two bytes of the table are identical to those defined in a standard USB string descriptor, and up to 253 bytes of data can be defined by the vendor. Note that Vendor Defined HID LANGIDs allow a vendor to associate additional data with a standard usage. For Vendor Defined usages, the Usage Descriptor LANGID may also be used, since the definition of the Usage Descriptor depends on the Vendor Defined usage.
The data types supported by Usage Descriptors can expand on those already supported by standard USB descriptors. These can include 64-bit signed and unsigned integers, 32, 64 and 128-bit IEEE format floating

### 26 Universal Serial Bus HID Usage Tables

point, etc. The Usage Descriptor defined by the usage will provide detailed information about the data types that are used.
Figure 5: Vendor Defined Descriptor
Part | Offset/Size (Bytes) | Value | Description
bLength | 0/1 | Number | Size of this descriptor in bytes
bDescriptorType | 1/1 | Constant | String (assigned by USB)
Vendor Defined Data | 2/n (n <= 253) | Vendor Defined | Vendor defined fields

Universal Serial Bus HID Usage Tables | 27

## 4 Generic Desktop Page (0x01)

Table 6: Generic Desktop Page

Usage ID | Usage Name | Usage Type | Section
00 | Undefined
01 | Pointer | CP | 4.1
02 | Mouse | CA | 4.1
03 | Reserved
04 | Joystick | CA | 4.1
05 | Game Pad | CA | 4.1
06 | Keyboard | CA | 4.1
07 | Keypad | CA | 4.1
08 | Multi-axis Controller | CA | 4.1
09-2F | Reserved
30 | X | DV | 4.2
31 | Y | DV | 4.2
32 | Z | DV | 4.2
33 | Rx | DV | 4.2
34 | Ry | DV | 4.2
35 | Rz | DV | 4.2
36 | Slider | DV | 4.3
37 | Dial | DV | 4.3
38 | Wheel | DV | 4.3
39 | Hat switch | DV | 4.3
3A | Counted Buffer | CL | 4.6
3B | Byte Count | DV | 4.6
3C | Motion Wakeup | OSC | 4.3
3D | Start | OOC | 4.3
3E | Select | OOC | 4.3
3F | Reserved
40 | Vx | DV | 4.4
41 | Vy | DV | 4.4
42 | Vz | DV | 4.4
43 | Vbrx | DV | 4.4
44 | Vbry | DV | 4.4
45 | Vbrz | DV | 4.4
46 | Vno | DV | 4.4
47 | Feature Notification | DV,DF | 4.8
48-7F | Reserved

### 28 Universal Serial Bus HID Usage Tables

Usage ID | Usage Name | Usage Type | Section
80 | System Control | CA | 4.5
81 | System Power Down | OSC | 4.5
82 | System Sleep | OSC | 4.5.1
83 | System Wake Up | OSC | 4.5.1
84 | System Context Menu | OSC | 4.5
85 | System Main Menu | OSC | 4.5
86 | System App Menu | OSC | 4.5
87 | System Menu Help | OSC | 4.5
88 | System Menu Exit | OSC | 4.5
89 | System Menu Select | OSC | 4.5
8A | System Menu Right | RTC | 4.5
8B | System Menu Left | RTC | 4.5
8C | System Menu Up | RTC | 4.5
8D | System Menu Down | RTC | 4.5
8E | System Cold Restart | OSC | 4.5.1
8F | System Warm Restart | OSC | 4.5.1
90 | D-pad Up | OOC | 4.7
91 | D-pad Down | OOC | 4.7
92 | D-pad Right | OOC | 4.7
93 | D-pad Left | OOC | 4.7
94-9F | Reserved
A0 | System Dock | OSC | 4.5.1
A1 | System Undock | OSC | 4.5.1
A2 | System Setup | OSC | 4.5.1
A3 | System Break | OSC | 4.9
A4 | System Debugger Break | OSC | 4.9
A5 | Application Break | OSC | 4.9
A6 | Application Debugger Break | OSC | 4.9
A7 | System Speaker Mute | OSC | 4.5.1
A8 | System Hibernate | OSC | 4.5.1
A9-AF | Reserved
B0 | System Display Invert | OSC | 4.10
B1 | System Display Internal | OSC | 4.10
B2 | System Display External | OSC | 4.10
B3 | System Display Both | OSC | 4.10
B4 | System Display Dual | OSC | 4.10
B5 | System Display Toggle Int/Ext | OSC | 4.10
B6 | System Display Swap Primary/Secondary | OSC | 4.10

Universal Serial Bus HID Usage Tables | 29
Usage ID | Usage Name | Usage Type | Section
B7 | System Display LCD Autoscale | OSC | 4.10
B8-FFFF | Reserved

## 4.1 Application Usages

Pointer | CP – A collection of axes that generates a value to direct, indicate, or point user intentions to an application.
Mouse | CA – A hand-held, button-activated input device that when rolled along a flat surface, directs an indicator to move correspondingly about a computer screen, allowing the operator to move the indicator freely in select operations or to manipulate text or graphics. A mouse typically consists of two axes (X and Y) and one, two, or three buttons.
Joystick | CA – A manual control or cursor device. A joystick minimally consists of two variable axes (X and Y) and two buttons. A joystick is typically a rotational motion sensor. However, for legacy reasons, it is defined using linear axes.
| Traditionally, a joystick driver applies its own scaling to values returned from a joystick. That is, the driver simply linearizes and translates the range of values generated by the stick into normalized values between 0 and 64K, where 32K is centered. The application (game) then interprets the normalized values as necessary. Because of this, joysticks normally do not declare Units or Physical Minimum and Physical Maximum values for their axes. Depending on the driver, these items may be ignored if they are declared.
Game Pad | CA – A manual control or cursor device. A game pad minimally consists of a thumb-activated rocker switch that controls two axes (X and Y) and has four buttons. The rocker switch consists of four contact closures for up, down, right, and left.
Keyboard | CA – The primary computer input device. A Keyboard minimally consists of 103 buttons as defined by the Boot Keyboard definition. For details, see Appendix A of the HID Specification.
Keypad | CA – Any keyboard configuration that does not meet the minimum requirements of the Boot Keyboard. Keypad often refers to a supplementary calculator-style keyboard.
Multi-axis Controller | CA - An input device used to orient eyepoints and or objects in 3 dimensional space. A Multi-axis Controller typically consists of six, variable axes (X, Y, Z, Rx, Ry and Rz) and is used by CAD/digital content creation applications for model manipulation and visualization in 3D space. The device may incorporate zero or more buttons.

## 4.2 Axis Usages

For X, Y, Z, Rx, Ry, and Rz, the declaration of Units is optional. If Units is None or not declared, these values should be considered as dimensionless.

### 30 Universal Serial Bus HID Usage Tables

X | DV – A linear translation in the X direction. Report values should increase as the control’s position is moved from left to right.
Y | DV – A linear translation in the Y direction. Report values should increase as the control’s position is moved from far to near.
Z | DV – A linear translation in the Z direction. Report values should increase as the control’s position is moved from high to low (Z).
Rx | DV – A rotation about the X axis. Angular position report values follow the righthand rule.
Ry | DV – A rotation about the Y axis. Angular position report values follow the righthand rule.
Rz | DV – A rotation about the Z axis. Angular position report values follow the righthand rule.

## 4.3 Miscellaneous Controls

Slider | DV – A linear control for generating a variable value, normally in the form of a thumb slide in a slot. Report values should increase as controls are moved from near to far.
Dial | DV – A rotary control for generating a variable value, normally in the form of a knob spun by the index finger and thumb. Report values should increase as controls are spun clockwise. This usage does not follow the HID orientation conventions.
Wheel | DV – A rotary control for generating a variable value, normally rolled, unlike a dial. Report values should increase as controls are rolled forward, away from the user. This usage does not follow the HID orientation conventions.
Hat Switch | DV – A specialized mechanical configuration of switches generating a variable value with a null state. The switches are arranged around a springloaded knob. When the knob is tilted in the direction of a switch, its contacts are closed. A typical example is four switches that are capable of generating information about four possible directions in which the knob can be tilted. Intermediate positions can also be decoded if the hardware allows two switches to be reported simultaneously.
Motion Wakeup | DF – Enables the generation of a USB remote wakeup when the device detects motion. Motion Wakeup is always enabled after a USB Reset event is detected by the device. Then host can also assume that the state of the Motion Wakeup flag is maintained while the device is suspended.
| For example, a mouse may generate a remote wakeup when a button is pressed or when it is moved. For some implementations, a laptop user may want to disable the wakeup on motion because it draws more power.
Start | OOC - Session start button. Initiates a session within an application .
Select | OOC - Application option select button. Selects application configuration options.

Universal Serial Bus HID Usage Tables | 31

## 4.4 Vector Usages

For the usages Vx, Vy, Vz, Vbrx, Vbry, Vbrz, and Vno, Units are always required to determine the meaning of the vector. Rotational vectors are also identified by Units. These usages are used when declaring velocity, acceleration, force, electric field, and similar kinds of vectors in the respective direction and frame of reference.
Vx | DV – A vector in the X direction. Report values should increase as the vector
increases in the positive X direction (from left to right). Negative values represent vectors in the negative X direction.
Vy | DV – A vector in the Y direction. Report values should increase as the vector
increases in the positive Y direction (from far to near). Negative values represent vectors in the negative Y direction.
Vz | DV – A vector in the Z direction. Report values should increase as the vector
increases in the positive Z direction (from high to low). Negative values represent vectors in the negative Z direction.
Vbrx | DV – A vector in the X direction relative to the body of an object. Report
values should increase as the vector increases in the positive X direction (forward). Negative values represent vectors in the negative X direction. X is the “forward” axis for an object.
Vbry | DV – A vector in the Y direction relative to the body of an object. Report
values should increase as the vector increases in the positive Y direction (to the right from an observer facing forward on the object). Negative values represent vectors in the negative Y direction.
Vbrz | DV – A vector in the Z direction relative to the body of an object. Report
values should increase as the vector increases in the positive Z direction (down from an observer facing forward on the object). Negative values represent vectors in the negative Z direction.
Vno | DV– A non oriented vector or value. The units define a physical measurement
not related to a specific axis or orientation. An example would be pressure or temperature.

## 4.5 System Controls

System controls are a special category of usages that affect the system as a whole. They are pulled together in a System Control collection to make them easy for system software to identify.
System Control | CA – A application-level collection that contains system-software-specific
usages. System software will search specifically for this collection for those controls that affect the system globally.
System Context Menu | OSC – Evokes a context-sensitive menu.
System Main Menu | OSC – Evokes the OS main-level selection menu.
System App Menu | OSC – Displays an application-specific menu.
System Menu Help | OSC – Displays the help menu.
System Menu Exit | OSC – Exits a menu.
System Menu Select | OSC – Selects a menu item.

### 32 Universal Serial Bus HID Usage Tables

System Menu Right | RTC – Menu select right.
System Menu Left | RTC – Menu select left.
System Menu Up | RTC – Menu select up.
System Menu Down | RTC – Menu select down.

### 4.5.1 Power Controls

Power controls can step the system through the following states: Full Power, Low Power, and Power Down. The state diagram is shown in the following figure.
Figure 6: System Power States

Power control usages found in a System Control collection affect system level power. Those declared outside of a System Collection affect device level power.

System Power Down | OSC – Asserted when the intended action is to initiate system-wide power down now from Full Power or Sleep states.
System Sleep | OSC – Asserted when the intended action is to initiate system-wide low power mode now. If the system is already in the Low Power state, there is no effect.
System Wake Up | OSC – Asserted when the intended action is to initiate system-wide Full Power state now. If the system is already in the Full Power, there is no effect.
System Cold Restart | OSC – Asserted when the intended action is to restart the system at the most primitive level, similar to at Power Up
System Warm Restart | OSC – Asserted when the intended action is to restart the operating system but not necessarily the lowest level functions such as BIOS enumeration and RAM checks.
System Dock | OSC – Asserted when the intended action is to prepare a portable system for docking with a docking station.

Universal Serial Bus HID Usage Tables | 33
System Undock | OSC – Asserted when the intended action is to prepare a portable system for
removal from a docking station.
System Setup | OSC – Asserted when the intended action is to enter the BIOS-level system
setup program
System Speaker Mute | OSC – Asserted when the intended action is to mute the system speaker.
System Hibernate | OSC – Asserted when the intended action is to place the system in a
"deeper" sleep state than System Sleep

## 4.6 Buffered Bytes

The following usages provide a standard way of defining the operation of a buffered-byte field where the number of valid bytes in the field is less than the total number of bytes in the field and the vendor does not define a NoOp value to mark unused bytes.
When declaring a buffered-byte field, the global item Report Size should always be set to 8 (for byte cells), and the Report Count should be equal to the maximum size of the buffer to be transferred.
Counted Buffer | CL – Used with buffered –byte data to indicate the number of valid bytes in
the buffered-byte field. This collection always contains two field declarations: Byte Count and a usage that names the purpose of the buffered-byte field. The Main item associated with the purpose usage will always have the Buffered Bytes attribute set.
Byte Count | DV – Defines a report field that indicates the number of meaningful data
bytes in an associated buffered-byte field.

## 4.7 Direction Pads

A Direction Pad or D-Pad control is mechanically identical to a hatswitch, however for legacy reasons their data is interpreted as X and Y axes rather than as an angular direction.
D-pads are typically defined as a pair of X and Y axes that are contained in a logical Pointer collection. There are cases where an application may be interested in the raw D-pad data. The following usages are defined in a report descriptor as single bit fields that identify the current state of the position switches in the D-pad.
Note: A device may declare a Pointer collection with X and Y axes, and D-pad usages for the same control. An application can determine which data format best suits it's needs.
D-pad Up | OOC – Indicates that top of a Direction Pad is pressed
D-pad Down | OOC – Indicates that bottom of a Direction Pad is pressed
D-pad Right | OOC – Indicates that right side of a Direction Pad is pressed
D-pad Left | OOC – Indicates that left side of a Direction Pad is pressed

### 34 Universal Serial Bus HID Usage Tables

## 4.8 Feature Notifications

It may be useful to alert the host that the contents of a Feature report have changed without redundantly declaring a usage in an Input report, especially is the changes are only occasional. The Feature Notification usages provides a mechanism for doing this.
Feature Notification | DV – This usage is declared in an Input report and is used as a notification to the host that the contents of a specific Feature report has changed.
| If Report IDs are declared in the device's report descriptor then the Report Size of the Feature Notification must be greater than 1, and the Feature Notification field contains the Report ID of the Feature report that whose contents have changed. A zero value indicates that no Feature reports have changed. Multiple Feature report IDs can be reported in a single Input report by declaring the Report Count to be greater than 1.
| If Report IDs are not declared in the device's report descriptor then the Report Size of the Feature Notification equals 1, and the Input report field equals 1 if the Feature report contents have changed. A zero value indicates that no Feature reports have changed.
| When a valid Feature Notification is received, the host must issue a GetReport(Feature) request to the device with the appropriate report ID.

## 4.9 Software Flow Controls

The following usages provide standard controls to break into the current operation of the system.
System Break | OSC – Asserted when the intended action is to acquire the attention of the operating system in order to control applications. This operation could interrupt all running applications.

System Debugger Break OSC - Asserted when the intended action is to break into the operating
| system debugger. If no OS debugger is running, the control is ignored.
Application Break | OSC - Asserted when the intended action is to acquire the attention of an application. This operation interrupts only the foremost running application.

Application Debugger Break
| OSC - Asserted when the intended action is to break into the application debugger. If no application debugger is running, the control is ignored.

## 4.10 System Display Controls

Many systems currently support multiple displays. Of special note are portable systems with captive displays that may be connected to external displays. The following usages provide standard controls for common display control functions:
System Display Invert OSC - Causes the display to render in inverted colors.
System Display Internal OSC - Causes the system to use the captive display as the primary display. System Display External OSC - Causes the system to use the external display as the primary display. System Display Both OSC - Causes the system to use both internal and external displays as the primary display

Universal Serial Bus HID Usage Tables | 35
System Display Dual | OSC - Causes the system to use both internal and external displays as
primary and secondary displays.
System Display Toggle Int/Ext Mode
OSC - Causes a system to step between the modes as described above: System Display Internal
System Display External
System Display Both
System Display Swap Pri/Sec
OSC - Causes a system using two displays in dual mode to swap the primary and secondary displays.
System Display Toggle LCD Autoscale OSC - Causes a system with a non-scaleable geometry, such as an LCD, to scale the display image to fit the physical geometry of the display.

### 36 Universal Serial Bus HID Usage Tables

## 5 Simulation Controls Page (0x02)

This section provides detailed descriptions of the usages employed by simulation devices.

Table 7: Simulation Controls Page

Usage ID | Usage Name | Usage Type | Section
00 | Undefined
01 | Flight Simulation Device | CA | 5.2
02 | Automobile Simulation Device | CA | 5.3
03 | Tank Simulation Device | CA | 5.4
04 | Spaceship Simulation Device | CA | 5.2
05 | Submarine Simulation Device | CA | 5.5
06 | Sailing Simulation Device | CA | 5.5
07 | Motorcycle Simulation Device | CA | 5.6
08 | Sports Simulation Device | CA | 5.1
09 | Airplane Simulation Device | CA | 5.2
0A | Helicopter Simulation Device | CA | 5.2
0B | Magic Carpet Simulation Device | CA | 5.7
0C | Bicycle Simulation Device | CA | 5.6
0D – 1F | Reserved
20 | Flight Control Stick | CA | 5.2
21 | Flight Stick | CA | 5.2
22 | Cyclic Control | CP | 5.2
23 | Cyclic Trim | CP | 5.2
24 | Flight Yoke | CA | 5.2
25 | Track Control | CP | 5.4
26 –AF | Reserved
B0 | Aileron | DV | 5.2
B1 | Aileron Trim | DV | 5.2
B2 | Anti-Torque Control | DV | 5.2
B3 | Autopilot Enable | OOC | 5.2
B4 | Chaff Release | OSC | 5.2
B5 | Collective Control | DV | 5.2
B6 | Dive Brake | DV | 5.2
B7 | Electronic Countermeasures | OOC | 5.2
B8 | Elevator | DV | 5.2
B9 | Elevator Trim | DV | 5.2
BA | Rudder | DV | 5.2
BB | Throttle | DV | 5.2
BC | Flight Communications | OOC | 5.2

Universal Serial Bus HID Usage Tables | 37
Usage ID | Usage Name | Usage Type | Section
BD | Flare Release | OSC | 5.2
BE | Landing Gear | OOC | 5.2
BF | Toe Brake | DV | 5.2
C0 | Trigger | MC | 5.2
C1 | Weapons Arm | OOC | 5.2
C2 | Weapons Select | OSC | 5.2
C3 | Wing Flaps | DV | 5.2
C4 | Accelerator | DV | 5.3
C5 | Brake | DV | 5.3
C6 | Clutch | DV | 5.3
C7 | Shifter | DV | 5.3
C8 | Steering | DV | 5.3
C9 | Turret Direction | DV | 5.4
CA | Barrel Elevation | DV | 5.4
CB | Dive Plane | DV | 5.5
CC | Ballast | DV | 5.5
CD | Bicycle Crank | DV | 5.6
CE | Handle Bars | DV | 5.6
CF | Front Brake | DV | 5.6
D0 | Rear Brake | DV | 5.6
D1-FFFF | Reserved

## 5.1 Sports Simulation Device

Usages employed by Stick Devices and Exercise Machines are defined on the Sports Controls page. For details, see Section 7, “Sport Controls Page (0x04).”
Sports Simulation
Device

CA – This usage definition allows a device to be generally classified as one that uses standard controls found on a sports simulation device.

## 5.2 Flight Simulation Devices

Flight Simulation
Device

CA – This usage definition allows a device to be generally classified as one that uses the standard controls found on an airplane.
Spaceship Simulation
Device

CA – This usage definition allows a device to be generally classified as one that uses standard controls found on a spaceship.
Airplane Simulation
Device

CA – This usage definition allows a device to be generally classified as one that uses standard controls found on an airplane.
Helicopter Simulation
Device

CA – This usage definition allows a device to be generally classified as one that uses standard controls found on a helicopter.

### 38 Universal Serial Bus HID Usage Tables

Aileron | DV – An aileron is one of two movable flaps on the wings of an airplane that can be used to control the plane’s rolling and banking movements. In the zero position the ailerons are centered, positive values will move the right aileron up and the left aileron down, and negative values will have the opposite effect on the ailerons.
Aileron Trim | DV – Allows fine adjustment of the Aileron position. The zero position is the nominal position, positive values will move the right aileron up and the left aileron down, and negative values will have the opposite effect on the ailerons.
Anti-Torque Control | DV – This control mechanically behaves the same as rudder pedals; as one is pushed forward, the other pushes back. In a helicopter, this controls the pitch of the tail blade to spin the helicopter in place. The zero position is centered, positive values rotate right, and negative values rotate left.
Autopilot Enable | OOC – This control enables or disables an airplane’s autopilot. This should be a toggle switch, but it is typically implemented as a pushbutton.
Chaff Release | OSC – Chaff is strips of metal, foil, or glass fiber with a metal content, cut into various lengths and having varying frequency responses. It is used to reflect electromagnetic energy as a radar countermeasure. These materials, usually dropped from aircraft, also can be deployed from shells or rockets. Typically this a pushbutton that initiates a release of a fixed amount of material.
Collective Control | DV – This control is specifically for a helicopter. It controls the vertical acceleration or lift of the helicopter. The zero position is centered (level flight), positive values accelerate up, and negative values accelerate down.
Cyclic Control | CP – This control is specifically for a helicopter. A cyclic control is a stick between the pilot’s legs that moves in two axes. It controls the swash plate, which in turn controls horizontal acceleration of the helicopter. The zero position is centered, positive Y values accelerate forward, and negative Y values accelerate backward. Positive X values accelerate right, and negative X values accelerate left. This collection will contain X and Y axes.
Cyclic Trim | CP – This control is specifically for a helicopter. Cyclic Trim allows fine adjustment of the cyclic position in two dimensions. The zero position is the nominal position, positive values adjust the baseline acceleration right or forward, and negative values adjust the baseline acceleration left or backward, respectively. This collection will contain X and Y axes.
Dive Brake | DV – A flap that can be extended on an aircraft to increase drag and reduce the speed of descent. It is typically implemented as a lever that generates a dimensionless value between no braking (0) and full braking.
Electronic Countermeasures | OOC – A pushbutton that enables electronic countermeasures. This is typically active radar jamming; however Chaff (radar) or Flare (infrared) can be invoked.
Elevator | DV – A movable control surface, usually attached to the horizontal stabilizer of an aircraft, that is used to produce motion up or down. The zero position is centered, positive values raise the elevator, and negative values lower the elevator.

Universal Serial Bus HID Usage Tables | 39
Elevator Trim | DV – Elevator Trim allows fine adjustment of the Elevator position. The zero
position is the nominal position, positive values are elevator offset up, and negative values are elevator offset down.
Flight Communications OOC – In combat aircraft, a communication (comm) button is usually positioned under the index finger. Typically this is a two-position pushbutton where the first position enables communications with the crew and the second position enables the transmitter for communication external to the plane.
Flare Release | OSC – A flare is a device that produces a bright light for signaling,
illumination, identification, or heat for infrared missile countermeasures. Typically this is a pushbutton that releases a fixed number of flares.
Flight Control Stick CA – A Flight Control Stick controls the Pitch and Roll of an airplane. It looks like a joystick. The stick may be pushed forward or pulled back to move the tail elevator down or up, respectively. Pushing forward causes the plane to nose down. Tilting the stick right and left alters the position of the ailerons. In the zero position the ailerons are centered, tilting the stick to the right will move the right aileron up and the left aileron down, and tilting the stick to the left direction will have the opposite effect on the ailerons. Mechanically, a stick presents two degrees of rotational freedom with approximately a +/–45° range. However, these axes are represented as Generic Desktop Page translational axes X (Roll) and Y (Pitch).
Flight Stick | CA – A Flight Stick defines a class of device commonly used for flight
simulator games. For a device to qualify as a Flight Stick, it must support at least two axes (Pitch and Roll), a trigger button, three additional buttons, and a hat switch. A Flight Stick is a functional subset of a Flight Control Stick.
Landing Gear | OOC – A control for raising or lowering an airplane’s landing gear. This
should be a toggle switch, but it is typically implemented as pushbutton.
Rudder | DV – The zero position is centered, positive values turn right, and negative
values turn left.
Toe Brake | DV – A device for slowing or stopping the motion of an airplane when it is
on the ground. Typically, Toe Brakes consist of two foot pedals that affect the left and right brakes, respectively. Control of the Toe Brakes can allow steering of the plane as well as braking when it is on the ground. An analog Toe Brake generates a dimensionless value between 0 and full scale. In some implementations, the Toe Brake can simply be a pushbutton (full on or off).
Throttle | DV – A valve that regulates the flow of a fluid, such as the valve in an
internal-combustion engine that controls the amount of vaporized fuel entering the cylinders. A lever or pedal controlling such a valve generates a dimensionless value between 0 and full scale.
Trigger | MC – A lever pressed by the finger to release or activate a mechanism,
typically used to discharge a firearm. However, a Trigger can be used for many devices. In combat airplanes the Trigger is usually positioned under the thumb; for a gun it would be positioned under the index finger. Typically this is implemented as a pushbutton.
Weapons Arm | OOC – This device is normally a covered toggle switch that must be selected
to enable the weapons system.

### 40 Universal Serial Bus HID Usage Tables

Weapons Select | OSC – This device can either be a pushbutton that steps through the available weapons or a radio button that selects them individually.
Wing Flaps | DV – Wing flap controls are usually powered either hydraulically or by electric motors, and are used for low-speed control of an airplane. A flap generates a value between 0 and full extension.
Flight Yoke | CA – A flight yoke (also called a control wheel) controls the pitch and roll of an airplane. It looks like a bow tie grasped by both hands. The yoke at which the pilot sits may be pushed forward or pulled back to move the tail elevator down or up, respectively. In the zero position the elevator is centered for level flight. Pushing forward on the yoke causes the plane to nose down and generates negative values. Pulling back on the yoke causes the plane to nose up and generates positive values.
| Rotating the yoke alters the position of the ailerons. In the zero position the ailerons are centered. Rotating the yoke in a clockwise direction will move the right aileron up and the left aileron down and generate incrementing values. Rotating the yoke in the counterclockwise direction will have the opposite effect on the ailerons and generate decrementing values.

## 5.3 Automobile Simulation Devices

Automobile Simulation Device | CA – This usage definition allows a device to be generally classified as one that uses the standard controls found in an automobile or truck.
Accelerator | DV – A device, especially the gas pedal of a motor vehicle, for increasing speed. An Accelerator is a dimensionless single degree-of-freedom dynamic value, where the range of values is from zero to maximum acceleration.
Brake | DV – A device for slowing or stopping motion, as of a vehicle, especially by contact friction. A Brake can be an On/Off Control or a dimensionless single degree-of-freedom dynamic value, where the range of values is from zero to maximum braking.
Clutch | DV – A device for disengaging the transmission of a vehicle to allow shifting of gears. A Clutch can be a generic button or a dimensionless single degree- of-freedom dynamic value, where the range of values is from zero to maximum clutch actuation.
Shifter | DV – A device for shifting gears in a vehicle. A Shifter is a specialized mechanical configuration of a radio button. A zero value is returned when the shifter is in the neutral position. Positive values indicate the forward gear and negative values indicate the reverse gear that the device is in.
Steering | DV – A steering wheel is a single degree-of-freedom device that rotates about an axis. The zero position is always the neutral or “straight ahead” position, with positive values turning clockwise and negative values turning counterclockwise. If the Coordinate Values Wrap attribute is set, the steering wheel can be turned past 360 degrees.

Universal Serial Bus HID Usage Tables | 41

## 5.4 Tank Simulation Devices

Tank Simulation
Device

CA – This usage definition allows a device to be generally classified as one that uses standard controls found in a tank or a treaded vehicle.
Track Control | CP – A device for controlling the direction and velocity of a vehicle that is
driven by tracks. There can be either two sticks with one degree of freedom or a single stick with two degrees of freedom:
In the two-stick case, the neutral position is when the stick is centered (zero). Pushing the stick forward causes forward acceleration (positive values), and pulling it back causes reverse acceleration (negative values). The righthand and lefthand controls will affect the corresponding side of the vehicle.
In the one-stick case, forward/backward acceleration works the same as in the two-stick case. However, right or left movement of the stick determines the amount of power applied to the respective track. When the stick is centered horizontally, equal amounts of power are applied to both tracks, generating a zero output value. Moving the stick to the right will generate positive values, and moving the stick to the left will generate negative values. A Tank Track Control is a dimensionless analog entity.
Turret Direction | DV – This control determines the right-to-left positioning of the tank turret. A
value of zero maintains the current orientation of the turret. A positive value turns the turret to the right and a negative value turns the turret to the left.
Barrel Elevation | DV – This control determines the elevation of the gun barrel in a turret. A
value of zero maintains the current orientation of the barrel. A positive value raises the barrel and a negative value lowers the barrel.

## 5.5 Maritime Simulation Devices

Submarine Simulation
Device

CA – Allows a device to be generally classified as one that uses the standard controls of a submarine.
Dive Plane | DV – Dive planes control the vertical ascent or descent of the submarine
under power. A zero value indicates level travel. Positive values indicate ascent, and negative values indicate descent. A Dive Plane is a dimensionless analog entity.
Ballast | DV – Ballast controls the vertical ascent or descent of the submarine. A zero
value indicates level travel. Positive values indicate ascent, and negative values indicate descent. A Ballast is a dimensionless analog entity.
Sailing Simulation
Device

CA – Allows a device to be generally classified as one that uses the standard controls of a sailboat.

### 42 Universal Serial Bus HID Usage Tables

## 5.6 Two-wheeled Simulation Devices

Motorcycle
Simulation Device

CA – Allows a device to be generally classified as one that uses the standard controls of a motorcycle.
Bicycle Simulation
Device

CA – Allows a device to be generally classified as one that uses the standard controls of a bicycle.
Bicycle Crank | DV – A foot-operated assembly of pedals attached to a crank that is used for powering a bicycle. The reported value is the rate that the crank turns per minute.
Handle Bars | DV – A steering control, held in both hands, for a motorcycle or bicycle. A zero output value indicates that the direction of travel is straight ahead. Pulling back on the right side turns the vehicle to the right and generates a positive output. Pulling back on the left side turns the vehicle to the left and generates a negative output.
Front Brake | DV – Engages the front brake of the motorcycle to slow the vehicle. A Front Brake can be a generic button or a dimensionless single degree-of-freedom analog entity, where the range of values is from zero to maximum braking.
Rear Brake | DV– Engages the rear brake of the motorcycle to slow the vehicle. A Rear Brake can be a generic button or a dimensionless single degree-of-freedom analog entity, where the range of values is from zero to maximum braking.

## 5.7 Miscellaneous Simulation Devices

Magic Carpet Simulation Device | CA – Allows a device to be generally classified as one that uses the standard control of a magic carpet. This control is a bar, grasped by both hands, that controls the Yaw, Pitch and Roll of the carpet.
| The bar, at which the pilot sits, may be pushed forward or pulled back to cause the carpet to dive or rise, respectively. In the zero position, the carpet is in level flight. Pushing forward on the bar causes the carpet to nose down and generates negative values. Pulling back on the bar causes the carpet to nose up and generates positive values.
| Turning the bar turns the carpet. In the zero position, the carpet travels straight ahead. Pulling back on the right side turns the carpet to the right and generates positive values. Pulling back on the left side turns the carpet to the left and generates negative values.
| Rotating the bar rolls the carpet. In the zero position, the carpet travels level. Rotating the bar in a clockwise direction rolls the carpet to the right and generates positive values. Rotating the bar in the counterclockwise direction rolls the carpet to the left and generates negative values.

Universal Serial Bus HID Usage Tables | 43

## 6 VR Controls Page (0x03)

Virtual Reality controls depend on designators to identify the individual controls. Most of the following are usages are applied to the collections of entities that comprise the actual device.

Table 8: VR Controls Page

Usage ID | Usage Name | Usage Type
00 | Unidentified
01 | Belt | CA
02 | Body Suit | CA
03 | Flexor | CP
04 | Glove | CA
05 | Head Tracker | CP
06 | Head Mounted Display | CA
07 | Hand Tracker | CA
08 | Oculometer | CA
09 | Vest | CA
0A | Animatronic Device | CA
0B-1F | Reserved
20 | Stereo Enable | OOC
21 | Display Enable | OOC
22-FFFF | Reserved
Belt | CA – A Belt wraps around the user’s waist. A tracker would be centered in the small of the user’s back to identify the orientation of the user’s hips.
Body Suit | CA – Generally classifies a device as one that uses the standard controls found in a Body Suit. A Body Suit typically has a large number of position sensors typically fixed to the major joints of the body, such as the ankles, knees, hips, shoulders, elbows, wrists and head, for measuring the angle and movement of the wearer’s joints and limbs.
Flexor | CP – A Flexor describes the angle of bend of a joint or limb in the body. The designator is used to determine which joint a specific Flexor entity represents.
Glove | CA – A Glove reports the positions of the fingers. Up to 20 angular values can be reported. Designators are used to determine the degrees of freedom that the Glove device is capable of reporting.
Head Tracker | CP – A Head Tracker represents the position and/or orientation of the head in space. The axes are oriented such that, in the zero position, the user is looking from the positive Z axis to the negative Z axis. The positive Y axis is extends vertically from the top of the user's head.
Head Mounted Display | CA – A Head Mounted Display (HMD) presents the following parameters to the user: Vbrx, Vbry, and Vbrz. Stereo Enable and Display Enable are optional usages that can be included in an HMD collection.

### 44 Universal Serial Bus HID Usage Tables

Stereo Enable | OOC – Selects the display mode of the HMD. A value of 0 selects monoscopic mode and 1 selects stereoscopic mode.
Display Enable | OOC – Enables the HMD video output. A value of 0 turns off the display and 1 turns it on.
Hand Tracker | CA – A Hand Tracker represents the position of the hand in space. A Hand Tracker attaches to the back of the hand. In the zero position, it is assumed that the hand is held upright with the extended thumb parallel to the Y axis and the fingers pointing in the negative Z direction
Oculometer | CA – An Oculometer identifies the direction in which the eye is looking in rotation about the X and Y axes. The designator for an Oculometer is always Eye.
Vest | CA – A Vest wraps around the user’s chest and abdomen. A tracker would be placed on the user’s back between the shoulder blades.
Animatronic Device | CA – An input device for the animation of mechanical or Computer Graphic Image “electronic” puppets. An animatronic device is engineered to fit a puppeteer’s or performer’s body (and/or head and/or face) and comfortably allow a wide range of physical freedom.
| An Animatronic Device measures the angle and movement of the wearer’s joints and limbs, which are then translated into the motion of a puppet, allowing the puppet to mimic the wearer’s movements. There is not necessarily a 1:1 mapping of human to puppet controls. A puppeteer’s arm may be used to control the movement of an elephant’s trunk, or hand controls may be used to control facial expressions. Designators are used to determine which puppeteer joint is being tracked. The controlling application will map these inputs to the electronic or mechanical device.

Universal Serial Bus HID Usage Tables | 45

## 7 Sport Controls Page (0x04)

Table 9: Sport Controls Page

Usage ID | Usage Name | Usage Type | Section
00 | Unidentified
01 | Baseball Bat | CA | 7.1
02 | Golf Club | CA | 7.1
03 | Rowing Machine | CA | 7.2
04 | Treadmill | CA | 7.2
05-2F | Reserved
30 | Oar | DV | 7.2
31 | Slope | DV | 7.2
32 | Rate | DV | 7.2
33 | Stick Speed | DV | 7.1
34 | Stick Face Angle | DV | 7.1
35 | Stick Heel/Toe | DV | 7.1
36 | Stick Follow Through | DV | 7.1
37 | Stick Tempo | DV | 7.1
38 | Stick Type | NAry | 7.1
39 | Stick Height | DV | 7.1
3A-4F | Reserved
50 | Putter | Sel | 7.1
51 | 1 Iron | Sel | 7.1
52 | 2 Iron | Sel | 7.1
53 | 3 Iron | Sel | 7.1
54 | 4 Iron | Sel | 7.1
55 | 5 Iron | Sel | 7.1
56 | 6 Iron | Sel | 7.1
57 | 7 Iron | Sel | 7.1
58 | 8 Iron | Sel | 7.1
59 | 9 Iron | Sel | 7.1
5A | 10 Iron | Sel | 7.1
5B | 11 Iron | Sel | 7.1
5C | Sand Wedge | Sel | 7.1
5D | Loft Wedge | Sel | 7.1
5E | Power Wedge | Sel | 7.1
5F | 1 Wood | Sel | 7.1
60 | 3 Wood | Sel | 7.1
61 | 5 Wood | Sel | 7.1

### 46 Universal Serial Bus HID Usage Tables

Usage ID | Usage Name | Usage Type | Section
62 | 7 Wood | Sel | 7.1
63 | 9 Wood | Sel | 7.1
64-FFFF | Reserved

## 7.1 Stick Devices

Stick devices are used in applications in which the user swings one object to make contact with another. Typical examples are a baseball bat and a golf club. These devices sense various quantities at the point of impact to determine the direction that the target (struck) object will go. The target object is a sphere. The Stick usages Speed, Face Angle, Heel/Toe, Follow Through, Tempo, and Height identify the measurement quantities.
Baseball Bat | CA – Primary input device for baseball simulation applications. Normally consists of a collection of Stick usages.
Golf Club | CA – Primary input device for golf simulation applications. Normally consists of a collection of Stick usages.
Stick Speed | DV – The velocity with which the stick strikes the target object. This can be expressed as collection of velocity values to provide a direction, or as an absolute magnitude where the Stick Face Angle provides the direction.
Stick Face Angle | DV – The direction in which the stick strikes the target object. In a golf simulation, this will be the horizontal angle and the vertical angle will be determined by the Stick Type. For Baseball Bats and other stick devices the direction is expressed as a three-dimensional vector.
Stick Heel/Toe | DV – Identifies the contact point relative to the striking surface. This helps to identify the “sweet spot.” This is reported as a relative value where zero is the sweet spot, positive values are away from the user, and negative values are towards the user.
Stick Follow Through | DV – In a golf simulation, the user strikes the ball, swings the club forward over the shoulders, then brings the club back to the tee. Stick Follow Through is a measure of the time that this process takes. Other stick devices may provide this parameter as well.
Stick Tempo | DV – In a golf simulation, the user starts the swing at the ball, swings the club back over the shoulders, then strikes the ball. Stick Tempo is a measure of the time that this process takes. Other stick devices may provide this parameter as well.
Stick Type | NAry – An array that identifies the type of golf club used.
Irons 1 – 11, Woods 1, 3, 5, 7, 9, Sand Wedge, Loft Wedge, Power Wedge, and Putter | Sel – Golf club stick types. Stick type determines the stick face angle.
Stick Height | DV – Height of contact point above the ground for stick device.

Universal Serial Bus HID Usage Tables | 47

## 7.2 Exercise Machines

Bicycles can be found in Section 7.1 .

Rowing Machine | CA – An exercise device that simulates rowing a boat. Usages typically found
in this collection are Oars and Rate. Rate is typically expressed in strokes per minute.
Oar | DV – Rowing repetition rate in strokes per minute. Left, right and two-
handed oars are distinguished with designators.
Treadmill | CA – An exercise device consisting of an endless moving belt on which a
person can walk or jog while remaining in one place. Usages typically found in this collection are Slope and Rate. The Rate is typically expressed in strokes per minute.
Rate | DV – Rate in miles per hour.
Slope | DV – Slope is measured in degrees. Positive angles are uphill, negative
angles are downhill, and 0° is level.

### 48 Universal Serial Bus HID Usage Tables

## 8 Game Controls Page (0x05)

Table 10: Game Controls Page

Usage ID | Usage Name | Usage Type | Section
00 | Undefined
01 | 3D Game Controller | CA | 8.1
02 | Pinball Device | CA | 8.2
03 | Gun Device | CA | 8.3
04-1F | Reserved
20 | Point of View | CP | 8.1
21 | Turn Right/Left | DV | 8.1
22 | Pitch Forward/Backward | DV | 8.1
23 | Roll Right/Left | DV | 8.1
24 | Move Right/Left | DV | 8.1
25 | Move Forward/Backward | DV | 8.1
26 | Move Up/Down | DV | 8.1
27 | Lean Right/Left | DV | 8.1
28 | Lean Forward/Backward | DV | 8.1
29 | Height of POV | DV | 8.1
2A | Flipper | MC | 8.2
2B | Secondary Flipper | MC | 8.2
2C | Bump | MC | 8.2
2D | New Game | OSC | 8.2
2E | Shoot Ball | OSC | 8.2
2F | Player | OSC | 8.2
30 | Gun Bolt | OOC | 8.3
31 | Gun Clip | OOC | 8.3
32 | Gun Selector | NAry | 8.3
33 | Gun Single Shot | Sel | 8.3
34 | Gun Burst | Sel | 8.3
35 | Gun Automatic | Sel | 8.3
36 | Gun Safety | OOC | 8.3
37 | Gamepad Fire/Jump | CL | 8.4.1
39 | Gamepad Trigger | CL | 8.4.1
3A-FFFF | Reserved

Universal Serial Bus HID Usage Tables | 49

## 8.1 3D Game Controller

The following controls support first-person games or those that are played through the eyes of the character that represents the player in the 3D world.
3D Game Controller | CA – A collection of 3D movement usages.
Point of View | CP – A collection of rotational axes (Rx, Ry, and Rz) that represent the
orientation of the user’s head in 3D space. If applied to a Hat Switch, only the Rz (Yaw) axis will be controlled.
Turn Right/Left | DV – Identifies the horizontal facing direction of the player’s hips (Rz =
Yaw). Turn Right/Left is a relative value where 0° is straight ahead, positive values turn right, and negative values turn left. The rate of rotation is determined by the application.
Pitch
Forward/Backward

DV – Identifies the vertical facing direction of the player’s hips (Rx = Pitch). Pitch Right/Left is a relative value where 0° is a vector pointing up from the players hips to the players head, positive values bend back, and negative values bend forward. The rate of rotation is determined by the application.
Roll Right/Left | DV – Identifies the vertical facing direction of the player’s hips (Ry = Roll).
Roll Forward/Backward is a relative value where 0° is a vector pointing up from the players hips to the players head, positive values lean left, and negative values lean right. The rate of rotation is determined by the application.
Move Right/Left | DV – This control allows the player to sidestep or move right and left without
changing the orientation of the hips. Move Right/Left is a relative value where 0 is no lateral motion, positive values move right, and negative move left. The rate of movement is determined by the application.
Move
Forward/Backward

DV – This control allows the player to move forward and backward in the direction (yaw) the hips are facing. Move Forward/Backward is a relative value where 0 is no motion, positive values move backward, and negative move forward. ¹ The rate of movement is determined by the application.
Move Up/Down | DV – This control allows the player to move up and down. It is assumed that
the player can fly, is swimming, or is at a ladder or a climbable wall. Move Up/Down is a relative value where 0 is no motion, positive values move down, and negative move up.¹
The rate of movement is determined by the application.
Lean Right/Left | DV – This control allows the player to lean right and left from the hips,
without changing the orientation of the hips, for example, to look around a corner. Lean Right/Left is a relative value where 0 is no lateral motion, positive values move right, and negative move left. The rate of movement is determined by the application.
Lean
Forward/Backward

DV – This control allows the player to lean forward and backward from the hips in the direction (yaw) the hips are facing. Lean Forward/Backward is a relative value where 0 is no motion, positive values move backward, and negative move forward.¹
The rate of movement is determined by the application.

1
These directions may appear counter-intuitive but they are consistent with the HID orientation conventions.

### 50 Universal Serial Bus HID Usage Tables

Height of POV | DV – This control allows the player to stand, squat, and crawl. Height of POV is a relative value where 0 is the normal standing position and positive values lower the player’s Point Of View. The maximum value as indicated by Logical Maximum is the crawling position, the median positive value is the squatting position, and negative values indicate the player is standing on tiptoes or flying. ¹

## 8.2 Pinball Device

Pinball is a game played on a device in which the player operates a plunger to shoot a ball down or along a slanted surface that has obstacles and targets.
Pinball Device | CA – A collection of usages representing the controls of a pinball game.
Flipper | MC – A button that actuates a bar that swings around a pivot to change the direction of the ball. A pair of right and left flippers normally resides at the near end of the table.
Secondary Flipper | MC – A button that actuates a bar that swings around a pivot to change the direction of the ball. Secondary flippers normally reside on the sides halfway up the table.
Bump | MC – A control that indicates that the flipper assembly has been shoved by the player to change the direction of the ball. This can be as simple as a switch or as complex as a 3D force vector.
New Game | OSC – A button that terminates any current game and reinitializes for a new game.
Shoot Ball | OSC – A control that indicates that the player has placed the ball into play. This can be as a switch or a force vector.
Player | OSC – A button that cycles through the number of players supported by the game.

## 8.3 Gun Device

A Gun Device is used in battle and war game simulations.
Gun Device | CA – A collection of Gun usages that describes a hand-held projectile weapon.
Gun Bolt | OOC – A control that indicates the state of the gun bolt. A value of 1 indicates that the bolt is locked and ready to fire, and 0 indicates that the bolt is open, ready for the next shell.
Gun Clip | OOC – A control that indicates whether the gun clip is inserted. A value of 1 indicates that the clip is inserted, and 0 indicates that the clip is missing.
Gun Selector | NAry – This control identifies the firing mode of the weapon. Typically it is a mutually exclusive set of usages for single shot, burst, and fully automatic firing that are presented as an array input.
Gun Single Shot | Sel – Selects a single shot each time the trigger is pulled.

Universal Serial Bus HID Usage Tables | 51
Gun Burst | Sel – Selects a short burst (three shots) each time the trigger is pulled.
Gun Automatic | Sel – Places the gun in fully automatic mode where it will fire continuously
while the trigger is pulled.
Gun Safety | OOC – A control that indicates whether safety is enabled. A value of 1
indicates that the gun is enabled to fire, and 0 indicates that gun will not fire when the trigger is pulled.

## 8.4 Gamepads

The following Usages are targeted at gamepads however they can be used for any devices.
Gamepads use Start and Select buttons allow simple menu control. Select allows auser to linearly step through application options. If an option can be varied (i.e. volume, game speed, etc.) then the D-pad is typically used to modify it's value. A user indicates the final acceptance of an option by pressing Start. Seethe Generic Desktop page for the Start and Select button usage definitions.
Gamepad recommendations
1) All gamepad controls should have associated Physical descriptors.
2) If a gamepad control is labeled an associated String descriptor should be declared.

### 8.4.1 Gamepad Button Collections

Usages in the Gamepad Button Collections are assigned from the Button Page where Button 1 is the easiest for the user to access. Ideally, Button 1 is under the users finger when it is at rest. Button 2 is the next easiest to access and so on. The default gamepad is assumed to have the D-pad under the users left thumb and the Fire/Jump buttons under the right thumb.
The individual Gamepad Button collections can also support "chorded" commands. A Chorded command is invoked by simultaneously pressing multiple buttons with multiple fingers. By separating the buttons into thumb and index finger groups it will be possible for an application to identify whether a gamepad can support chorded commands.
An application should assume that if more than one button is pressed (true) in a collection that only the first button pressed is true. Or the lowest Button (Usage ID) is pressed if two or more buttons in the same collection become true in the same report.
Gamepad Fire/Jump and Trigger buttons are defined with the following conventions: Button 0 is the primary (or easiest to access) button, Button 1 is the secondary button, Button 3 is the tertiary button, and so on. Designators can be applied if more detail is required.
Gamepad Fire/Jump | CL – A collection of gamepad buttons controlled by the user's thumb.
Gamepad Trigger | CL – A collection of gamepad buttons controlled by the user's index fingers.

### 52 Universal Serial Bus HID Usage Tables

## 9 Generic Device Controls Page (0x06)

This page provides usage definitions for controls can be on any type of device. Table 11: Generic Device Controls Page

Usage ID | Usage Name | Usage Type
00 | Unidentified
01-1F | Reserved
20 | Battery Strength | DV
21 | Wireless Channel | DV
22 | Wireless ID | DV
23-FFFF | Reserved
Battery Strength | DV - The current battery status. Proportion of battery life remaining where Logical Minimum and Logical Maximum define the range. Null values indicate unknown battery status.
Wireless Channel | DV - The logical wireless channel that a wireless device is using. Actual values depend on the wireless protocol used.
Wireless ID | DV - Uniquely identifies a wireless device in a wireless subsystem. Actual values depend on the wireless protocol used.

Note: The relationship between a Wireless Channel and a Wireless ID is unspecified. Either or both can be used by a device.

Universal Serial Bus HID Usage Tables | 53
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

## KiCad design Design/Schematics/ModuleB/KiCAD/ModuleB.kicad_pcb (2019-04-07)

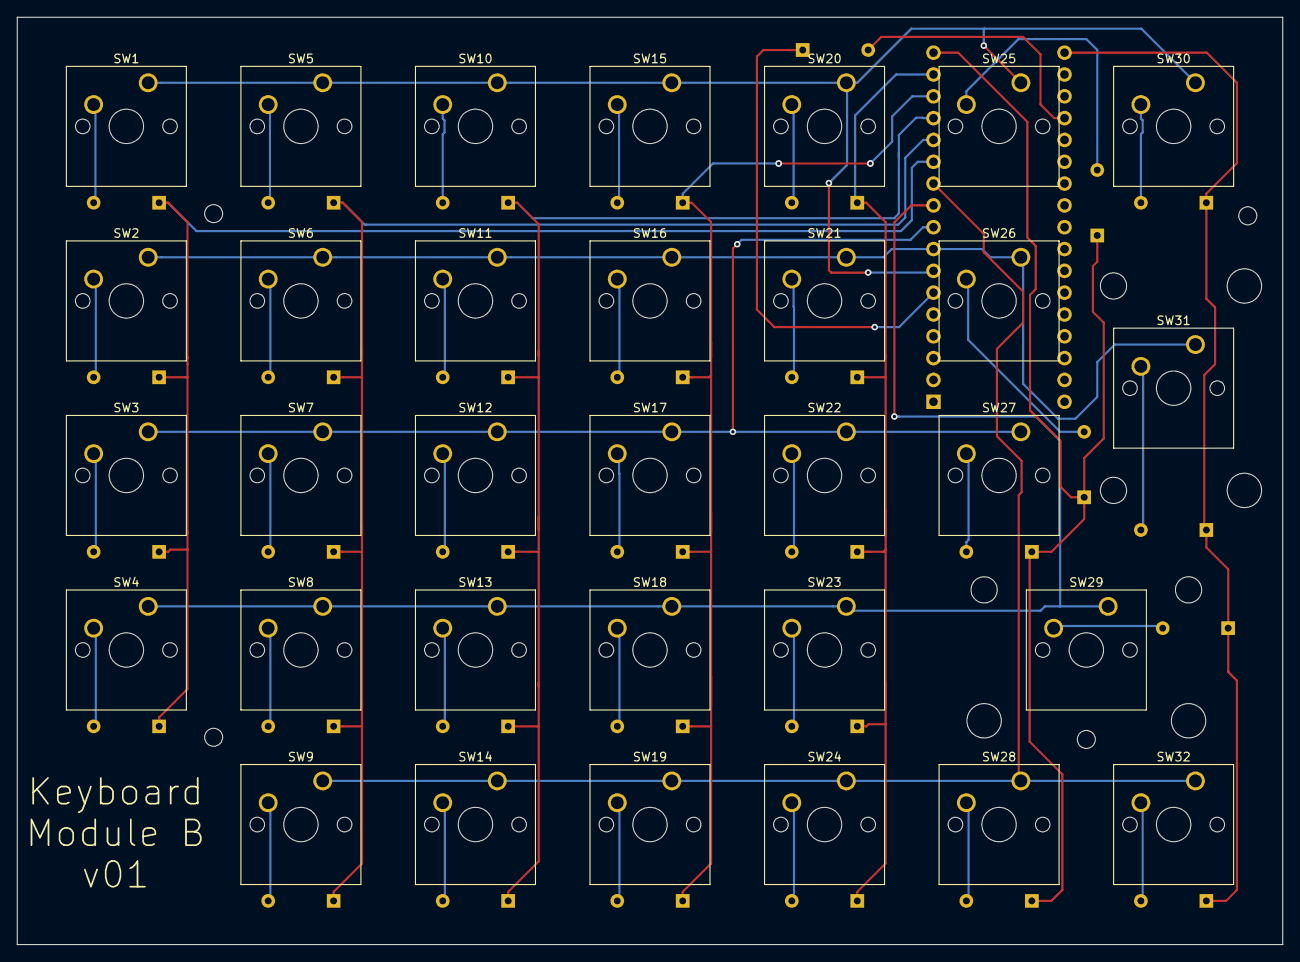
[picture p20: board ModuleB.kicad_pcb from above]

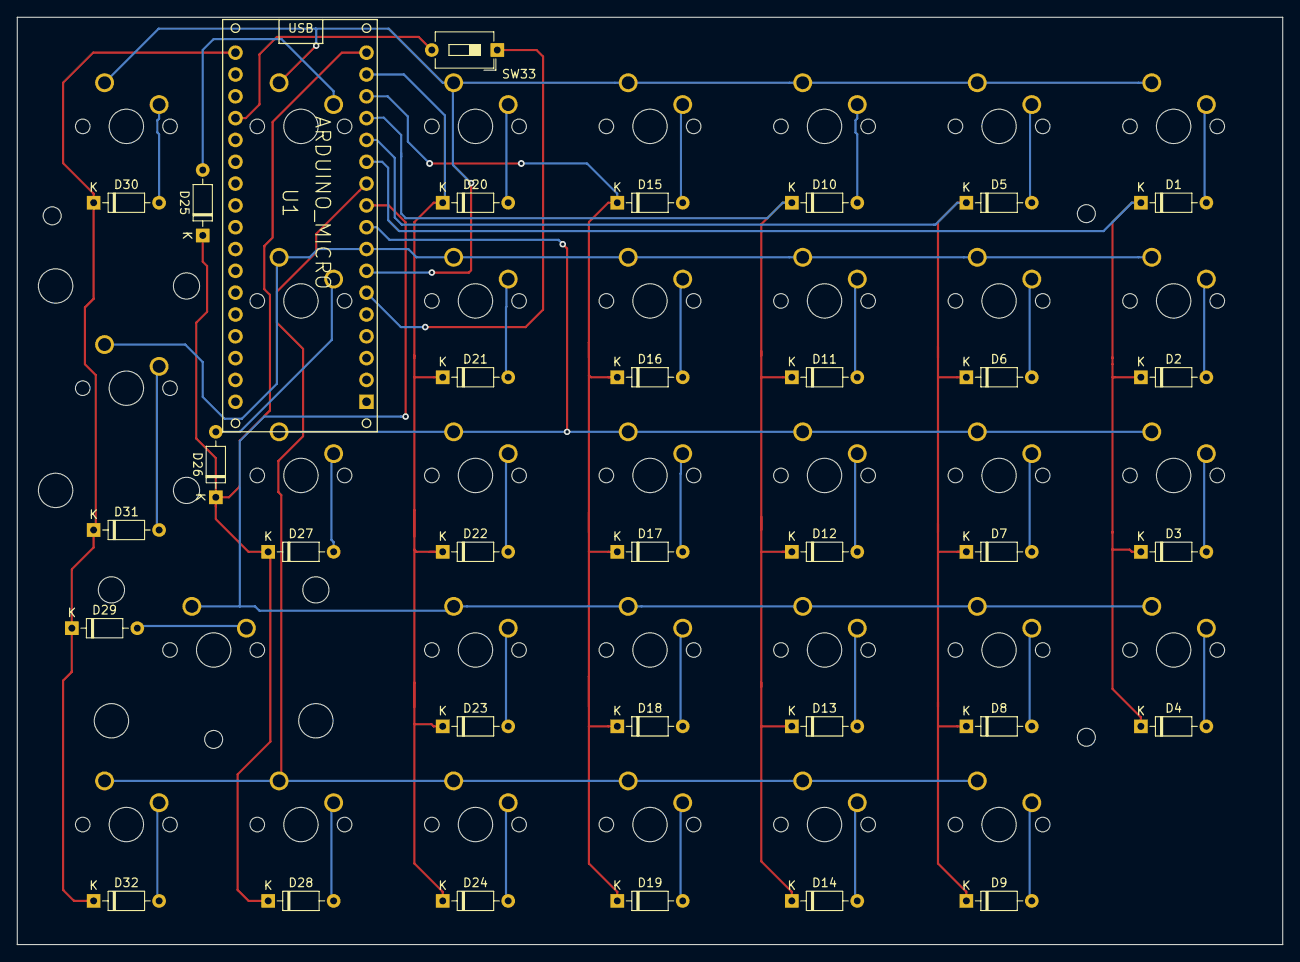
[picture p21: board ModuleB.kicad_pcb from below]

Board: 2 copper layers, 147.3 x 108.0 mm, 66 parts (34 on the bottom side), 46 nets.

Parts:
D1, D2, D3, D4, D5, D6, D7, D8, D9, D10, D11, D12, D13, D14, D15, D16, D17, D18, D19, D20, D21, D22, D23, D24, D25, D26, D27, D28, D29, D30, D31, D32: 1N4149; D_DO-35_SOD27_P7.62mm_Horizontal
SW1, SW2, SW3, SW4, SW5, SW6, SW7, SW8, SW9, SW10, SW11, SW12, SW13, SW14, SW15, SW16, SW17, SW18, SW19, SW20, SW21, SW22, SW23, SW24, SW25, SW26, SW27, SW28, SW30, SW32: SW_Push; SW_Cherry_MX1A_1.00u_PCB
SW29: SW_Push; SW_Cherry_MX1A_2.00u_PCB
SW31: SW_Push; SW_Cherry_MX1A_2.00u_Vertical_PCB
SW33: SW_Push; SW_DIP_SPSTx01_Slide_6.7x4.1mm_W7.62mm_P2.54mm_LowProfile
U1: ARDUINO_MICRO; ARDUINO_MICRO_SHIELD

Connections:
unnamed: D1.1, D2.1, D3.1, D4.1, U1.7
unnamed: D1.2, SW1.2
unnamed: D2.2, SW2.2
unnamed: D3.2, SW3.2
unnamed: D4.2, SW4.2
unnamed: D5.1, D6.1, D7.1, D8.1, D9.1, U1.8
unnamed: D5.2, SW5.2
unnamed: D6.2, SW6.2
unnamed: D7.2, SW7.2
unnamed: D8.2, SW8.2
unnamed: D9.2, SW9.2
unnamed: D10.1, D11.1, D12.1, D13.1, D14.1, U1.9
unnamed: D10.2, SW10.2
unnamed: D11.2, SW11.2
unnamed: D12.2, SW12.2
unnamed: D13.2, SW13.2
unnamed: D14.2, SW14.2
unnamed: D15.1, D16.1, D17.1, D18.1, D19.1, U1.10
unnamed: D15.2, SW15.2
unnamed: D16.2, SW16.2
unnamed: D17.2, SW17.2
unnamed: D18.2, SW18.2
unnamed: D19.2, SW19.2
unnamed: D20.1, D21.1, D22.1, D23.1, D24.1, U1.11
unnamed: D20.2, SW20.2
unnamed: D21.2, SW21.2
unnamed: D22.2, SW22.2
unnamed: D23.2, SW23.2
unnamed: D24.2, SW24.2
unnamed: D25.1, D26.1, D27.1, D28.1, U1.12
unnamed: D25.2, SW25.2
unnamed: D26.2, SW26.2
unnamed: D27.2, SW27.2
unnamed: D28.2, SW28.2
unnamed: D29.1, D30.1, D31.1, D32.1, U1.13
unnamed: D29.2, SW29.2
unnamed: D30.2, SW30.2
unnamed: D31.2, SW31.2
unnamed: D32.2, SW32.2
unnamed: SW1.1, SW5.1, SW10.1, SW15.1, SW20.1, SW25.1, SW30.1, U1.2
unnamed: SW2.1, SW6.1, SW11.1, SW16.1, SW21.1, SW26.1, SW31.1, U1.3
unnamed: SW3.1, SW7.1, SW12.1, SW17.1, SW22.1, SW27.1, U1.4
unnamed: SW4.1, SW8.1, SW13.1, SW18.1, SW23.1, SW29.1, U1.5
unnamed: SW9.1, SW14.1, SW19.1, SW24.1, SW28.1, SW32.1, U1.6
unnamed: SW33.1, U1.GND
unnamed: SW33.2, U1.A0

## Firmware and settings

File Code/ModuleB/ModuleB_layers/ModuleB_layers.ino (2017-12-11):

#include "Keyboard.h"
#include "Key.h"

/** Order of things
  	scan for pressed buttons
   save scan result in 'state'
   compare new state with last state
    if(state has changed) {
 		   check layer
 		   translate to scan codes (just check the layer, really)
 		   build
 		   send
 		   save state
 	  }
*/

const byte numCols = 7;
const byte numRows = 5;
const byte layers = 3; // Normal, raise, lower
const byte scanRounds = 2;

int blockPin  = A0;
int delayTimeInMSBetweenScans = 10;

// Setup matrix. Map the pins.
int cols[numCols] = {7, 8, 9, 10, 11, 12, 13};
int rows[numRows] = {2, 3, 4, 5, 6};

struct ModPosition{
  byte row;
  byte col;
  byte val;
};

const ModPosition raise = {4,2,1};
const ModPosition lower = {4,5,2};

uint8_t keys[layers][numRows][numCols] = {
  { // Normal (0)
    {Key::K6      , Key::K7    , Key::K8    , Key::K9     , Key::K0    , Key::DASH    , Key::EQUAL}
    , {Key::Y     , Key::U     , Key::I     , Key::O      , Key::P     , Key::OBRAKET , Key::RETURN}
    , {Key::H     , Key::J     , Key::K     , Key::L      , Key::COLON , Key::QUOTE   , Key::NONE}
    , {Key::N     , Key::M     , Key::COMMA , Key::DOT    , Key::SLASH , Key::NONE    , Key::BACKSPACE}
    , {Key::NONE  , Key::R_ALT , MOD::RAISE , Key::R_SUPR , Key::MENU  , MOD::LOWER   , Key::R_CTRL}
  }
  , { // Raise (1)
    {Key::F6     , Key::F7      , Key::F8      , Key::F9      , Key::F10   , Key::F11     , Key::F12}
    , {Key::NONE , Key::NONE    , Key::ARROW_U , Key::NONE    , Key::NONE  , Key::CBRAKET , Key::RETURN}
    , {Key::NONE , Key::ARROW_L , Key::ARROW_D , Key::ARROW_R , Key::NONE  , Key::TILDE   , Key::NONE}
    , {Key::NONE , Key::NONE    , Key::NONE    , Key::NONE    , Key::NONE  , Key::NONE    , Key::DELETE}
    , {Key::NONE , Key::R_ALT   , MOD::RAISE   , Key::R_SUPR  , Key::MENU  , MOD::LOWER   , Key::R_CTRL}
  }
  , { // Lower(2)
    {Key::NONE     , Key::NONE  , Key::NONE   , Key::NONE   , Key::NONE      , Key::NONE   , Key::NONE}
    , {Key::NONE   , Key::NONE  , Key::PGUP   , Key::NONE   , Key::PRNT_SCRN , Key::NONE   , Key::RETURN}
    , {Key::INSERT , Key::HOME  , Key::PGDWN  , Key::END    , Key::NONE      , Key::NONE   , Key::NONE}
    , {Key::NONE   , Key::NONE  , Key::NONE   , Key::NONE   , Key::NONE      , Key::NONE   , Key::BACKSPACE}
    , {Key::NONE   , Key::R_ALT , MOD::RAISE  , Key::R_SUPR , Key::MENU      , MOD::LOWER  , Key::R_CTRL}
  }
};

///////////////////////////
bool pressed[scanRounds][numRows][numCols] = {};
bool lastState[numRows][numCols] = {false};
bool state[numRows][numCols] = {false};
bool blocked = false;
uint8_t codes[numRows][numCols] = {Key::NONE};

///////////////////////////

void setup() {
  blocked = analogRead(blockPin) < 100;

  for (byte b = 0; b < numRows; ++b) {
    setupRow(rows[b]);
  }

  for (byte b = 0; b < numCols; ++b) {
    setupCol(cols[b]);
  }

  initKeyboard();
  Serial.begin(115200);
}

void setupRow(byte pin) {
  pinMode(pin, OUTPUT);
  digitalWrite(pin, HIGH);
}

void setupCol(byte pin) {
  pinMode(pin, INPUT_PULLUP);
}

///////////////////////////


void loop() {
  if (!blocked) {
    scan();
    if (stateHasChanged(lastState, state)) {
      buildAndSend(state);
      save(state);
    }
  }
}

/*******
  Scan
*******/
void scan() {
  for (byte b = 0; b < scanRounds; ++b) {
    debounce(b);
    delay(delayTimeInMSBetweenScans);
  }
  readState();
}

void debounce(byte pass) {
  for (byte b = 0; b < numRows; ++b) {
    pinLow(rows[b]);
    for (byte c = 0; c < numCols; ++c) {
      pressed[pass][b][c] = readPin(cols[c]);
    }
    pinHigh(rows[b]);
  }
}

void pinHigh(byte pin) {
  digitalWrite(pin, HIGH);
}
void pinLow(byte pin) {
  digitalWrite(pin, LOW);
}

bool readPin(byte pin) {
  if (!digitalRead(pin)) {
    return true;
  }
  return false;
}

void readState() {
  for (byte b = 0; b < numRows; b++) {
    for (byte c = 0; c < numCols; ++c) {
      bool isPressed = true;
      for (byte d = 0; d < scanRounds; ++d) {
        isPressed = isPressed && pressed[d][b][c];
      }
      state[b][c] = isPressed;
    }
  }
}

/********
  State
********/

bool stateHasChanged(bool lastState[numRows][numCols], bool state[numRows][numCols]) {
  for (byte b = 0; b < numRows; ++b) {
    for (byte c = 0; c < numCols; ++c) {
      if (lastState[b][c] != state[b][c]) {
        return true;
      }
    }
  }
  return false;
}

void save(bool state[numRows][numCols]) {
  for (byte b = 0; b < numRows; ++b) {
    for (byte c = 0; c < numCols; ++c) {
      lastState[b][c] = state[b][c];
    }
  }
}

/*****************
  Build and send
******************/

void buildAndSend(bool state[numRows][numCols]) {
  byte l = layer(state);
    
  for (byte b = 0; b < numRows; ++b) {
    for (byte c = 0; c < numCols; ++c) {
      if (state[b][c] == true) {
        addKeyToBuffer(keys[l][b][c]);
      }
    }
  }
  sendRest();
}

byte layer(bool state[numRows][numCols]) {
  if (state[lower.row][lower.col] == true) {
    return lower.val;
  } else if (state[raise.row][raise.col] == true) {
    return raise.val;
  } else {
    return 0;
  }
}

const byte keyLimit = 6;
byte keyPlace = 0;
uint8_t keyBuf[keyLimit];
uint8_t meta = 0x0;
void addKeyToBuffer(uint8_t key) {
  if (isKeyWithValue(key)) {
    if (isMeta(key)) {
      meta |= metaValue(key);
    } else {
      keyBuf[keyPlace++] = key;
    }

    if (keyPlace == keyLimit) {
      sendBuffer(meta, keyBuf);
    }
  }
}


void sendRest() {
  bool shouldSend = false;
  for (byte b = 0; b < keyLimit; ++b) {
    if (keyBuf[b] != 0x0) {
      shouldSend = true;
    }
  }
  if (shouldSend || stateHasChanged(lastState, state)) {
    sendBuffer(meta, keyBuf);
  }
}

void sendBuffer(uint8_t meta, uint8_t keyBuf[]) {
  sendKeyBuffer(meta, keyBuf);
  resetKeys();
}

void resetKeys() {
  for (byte b = 0; b < keyLimit; ++b) {
    keyBuf[b] = 0x0;
  }
  keyPlace = 0;
  meta = 0x0;
}

bool isKeyWithValue(uint8_t key) {
  return key != Key::NONE;
}

bool isMeta(uint8_t key) {
  if (key == Key::L_CTRL
      || key == Key::L_SHFT
      || key == Key::L_ALT
      || key == Key::L_SUPR
      || key == Key::R_CTRL
      || key == Key::R_SHFT
      || key == Key::R_ALT
      || key == Key::R_SUPR
     ) {
    return true;
  }
  return false;
}

uint8_t metaValue(uint8_t key) {
  switch (key) {
    case Key::L_CTRL:
      return Mod::LCTRL;
    case Key::L_SHFT:
      return Mod::LSHFT;
    case Key::L_ALT:
      return Mod::LALT;
    case Key::L_SUPR:
      return Mod::LSUPR;
    case Key::R_CTRL:
      return Mod::RCTRL;
    case Key::R_SHFT:
      return Mod::RSHFT;
    case Key::R_ALT:
      return Mod::RALT;
    case Key::R_SUPR:
      return Mod::RSUPR;
    default:
      return 0;
  }
}


/*****************
  Debugs
******************/

void printState() {
  Serial.print(" ");
  for (int j = 0; j < numCols; ++j) {
      Serial.print(" ");
      Serial.print(j);
  }
  for (int i = 0; i < numRows; ++i) {
    Serial.println();
    Serial.print(i);
    for (int j = 0; j < numCols; ++j) {
      Serial.print(" ");
      Serial.print(state[i][j], DEC);
    }
  }
  Serial.println();
}

void printLayer(){
  Serial.print("Lower: ");
  printPos(lower.row, lower.col);
  Serial.print(" || Raise: ");
  printPos(raise.row, raise.col);
  Serial.println();
}

void printPos(byte r, byte c){
  Serial.print(state[r][c], DEC);
}

void printLastState() {
  for (int i = 0; i < numRows; ++i) {
    Serial.println();
    for (int j = 0; j < numCols; ++j) {
      Serial.print(" ");
      Serial.print(lastState[i][j], DEC);
    }
  }
  Serial.println();
}

void printPressed() {
  for (int i = 0; i < numRows; ++i) {
    Serial.println();
    for (int j = 0; j < numCols; ++j) {
      Serial.print(" ");
      Serial.print(pressed[0][i][j], DEC);
    }
  }
  Serial.println();
}

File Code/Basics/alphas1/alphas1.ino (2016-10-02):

//	alphas1
//	Try to send letters and use a modifier

/*
Modifiers is a bitfield.
So this is how they should be corresponding.

bit 0: left control
bit 1: left shift
bit 2: left alt
bit 3: left GUI (Win/Apple/Meta key)
bit 4: right control
bit 5: right shift
bit 6: right alt
bit 7: right GUI
*/

struct Modifiers{
	uint8_t L_CTRL ;
	uint8_t L_SHIFT;
	uint8_t L_ALT  ;
	uint8_t L_META ;
	
	uint8_t R_CTRL ;
	uint8_t R_SHIFT;
	uint8_t R_ALT  ;
	uint8_t R_META ;
} mods = {
	0xE0
	, 0xE1
	, 0xE2
	, 0xE3

	, 0xE4
	, 0xE5
	, 0xE6
	, 0xE7
};

const int numModifiers = 8;
uint8_t modifiers[numModifiers] = {
	 mods.L_CTRL
	 , mods.L_SHIFT
	 , mods.L_ALT
	 , mods.L_META
	 , mods.R_CTRL
	 , mods.R_SHIFT
	 , mods.R_ALT
	 , mods.R_META
};

const int numRows = 3;
const int numCols = 3;
int rows[] = {4,5,6};
int cols[] = {10,11,12};

uint8_t lastFrame[8] = {0};

uint8_t key[numRows][numCols] = {
	{mods.L_CTRL, mods.L_SHIFT, 0x05},
	{0x06, 0x07, 0x08},
	{0x09, 0x0A, 0x0B}
};


int pressed[2][numRows][numCols] = {
	{
		{0,0,0},
		{0,0,0},
		{0,0,0}
	},
	{
		{0,0,0},
		{0,0,0},
		{0,0,0}
	}
};

int lastState[numRows][numCols] = {0};
int state[numRows][numCols] = {0};

/////////////

void setup() {
	Serial.begin(9600);
	for(int i=0; i<numRows; ++i){
		setupRow(rows[i]);
	}
	for(int i=0; i<numCols; ++i){
		setupCol(cols[i]);
	}

}

void setupRow(int pin){
	pinMode(pin, OUTPUT);
	digitalWrite(pin, HIGH);
}

void setupCol(int pin){
	pinMode(pin, INPUT_PULLUP);
}

/////////////

void loop() {
	scan();
	//printState();
	if(stateHasChanged(lastState, state)){
		buildBufferAndSend(state);
	}
	saveState(state);
	//delay(1000);
}

/*********
*  Scan  *
*********/
void scan(){
	debounce(0);
	delay(50);
	debounce(1);
	readState();
}

void debounce(int pass){
	for(int i=0; i<numRows; ++i){
		pinLow(rows[i]);
		for(int j=0; j<numCols; ++j){
			pressed[pass][i][j] = readPin(cols[j]);
		}
		pinHigh(rows[i]);
	}
}

void pinHigh(int pin){
	digitalWrite(pin, HIGH);
}

void pinLow(int pin){
	digitalWrite(pin, LOW);
}

int readPin(int pin){
	int val = digitalRead(pin);
	if(!val){
		return 1;
	}
	return 0;
}

void readState(){
	for(int i=0; i<numRows; ++i){
		for(int j=0; j<numCols; ++j){
			if(pressed[0][i][j] + pressed[1][i][j] == 2){
				state[i][j] = 1;
			} else {
				state[i][j] = 0;
			}
		}
	}
}

void printState(){
	for(int i=0; i<numRows; ++i){
		Serial.println();
		for(int j=0; j<numCols; ++j){
			Serial.print(" ");
			Serial.print(state[i][j], DEC);
		}
	}
		Serial.println();
	
}


/****************
*  State check  *
****************/

boolean stateHasChanged(int lastState[numRows][numCols], int state[numRows][numCols]){
	for(int i=0; i<numRows; ++i){
		for(int j=0; j<numCols; ++j){
			if(lastState[i][j] != state[i][j]){
				return true;
			}
		}
	}
	return false;
}

/********************************
*  Build, send, and save state  *
********************************/

void buildBufferAndSend(int state[numRows][numCols]){
	for(int i=0; i<numRows; ++i){
		for(int j=0; j<numCols; ++j){
			if(state[i][j] == 1){
				addKeyToBuffer(key[i][j]);
			}
		}
	}
	sendRest();
}


const int keyLimit = 6;
int keyPlace=0;
uint8_t keys[keyLimit];
uint8_t meta = 0x0;
void addKeyToBuffer(uint8_t key){
	if(isMeta(key)){
		meta|= metaValue(key);
	} else {
		keys[keyPlace++]=key;
	}

	if(keyPlace == keyLimit){
		uint8_t buf[8];
		buildBuffer(meta, keys, buf);
		send(buf);
		resetKeys();
	}
}

void sendRest(){
	boolean shouldSend = false;
	for(int i=0; i<keyLimit; ++i){
		if(keys[i] != 0x0){
			shouldSend = true;
		}
	}
	if(shouldSend || stateHasChanged(lastState, state)){
		uint8_t buf[8];
		buildBuffer(meta, keys, buf);
		send(buf);
		resetKeys();
	}
}

void resetKeys(){
	for(int i=0; i<keyLimit; ++i){
		keys[i] = 0x0;
	}
	meta = 0x0;
	keyPlace=0;
}

boolean isMeta(uint8_t key){
	for(int i=0; i<numModifiers; ++i){
		if(modifiers[i] == key){
			return true;
		}
	}
	return false;
}

uint8_t metaValue(uint8_t key){
	if( 0xDF < key < 0xE8){
		if(key == mods.L_CTRL){
			return 0b00000001;
		} else if (key == mods.L_SHIFT){
			return 0b00000010;
		} else if (key == mods.L_ALT){
			return 0b00000100;
		} else if (key == mods.L_META){
			return 0b00001000;
		} else if (key == mods.R_CTRL){
			return 0b00010000;
		} else if (key == mods.R_SHIFT){
			return 0b00100000;
		} else if (key == mods.R_ALT){
			return 0b01000000;
		} else if (key == mods.R_META){
			return 0b10000000;
		}
	}
	return 0x00;
}


void buildBuffer(uint8_t meta, uint8_t keys[], uint8_t buf[]){
	buf[0] = meta;
	buf[1] = 0x0; // Reserved
	buf[2] = keys[0];
	buf[3] = keys[1];
	buf[4] = keys[2];
	buf[5] = keys[3];
	buf[6] = keys[4];
	buf[7] = keys[5];
}


void send(uint8_t buf[]){
	Serial.write(buf, 8);
	//printMeta(buf[0]);
	//printState();
}

void printMeta(uint8_t metaKey){
	Serial.print(metaKey, HEX);
}

void saveState(int state[numRows][numCols]){
	for(int i=0; i<numRows; ++i){
		for(int j=0; j<numCols; ++j){
			lastState[i][j] = state[i][j];
		}
	}
}

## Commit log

2016-10-02 Add design and SCAD files.
    [moduleA-wireframe.scad, moduleB-wireframe.scad]
2016-10-02 Update ignore to allow hex. Added basic code. Added hex files needed for arduino UNO to be able to act as a keyboard (and arduino again). Added basic code for a numpad and som basic alphas. Also adde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
2016-10-09 Moved and renamed files. Put together a basic build of moduleA. No holes for USB done. Will see how this prints later. A bit worried about the integrity of the top part. Wondering if it will stay rig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
    [moduleA-backplate.scad, moduleA-backplate.stl, moduleA-build.scad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]
2016-10-09 Add the stl for moduleA build.
    [moduleA-build.stl]
2016-10-22 Add matrix schematics for the test code.
    [matrix.fzz]
2016-10-22 Move fritzproject to matrix dir.
    [matrix.fzz]
2016-12-22 Add work on ModuleA
    [ModuleA.fzz]
2016-12-23 Start working on the code for ModuleA.
    [ModuleA.fzz]
2016-12-27 ModuleA is shaping up. Segfaults ArduinoIDE when compiling though.
2016-12-27 Move mod-values to an enum. And set correct returntype on metaValue. Also, the compiler doesn't segfault now.
    [ModuleA.ino]
2017-01-05 Fix typo that turned out to be a major bug.
    [ModuleA.ino]
2017-05-07 Add print tests for key-sizes. The keys must fit the holes, obviously..
    [KeySize_15.5x13 .scad, KeySize_15.5x13.stl, KeySize_15.5x13_moreSpace .scad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]
2017-05-13 Add structure to the top so it doesn't bend.
    [beams.stl, cross-beams.scad, cross-beams.stl]
2017-05-14 New moduleA with a new design that should require fewer keys.
    [KeySize_15.2x12.5.scad, KeySize_15.2x12.5.stl, KeySize_15.2x12.6.scad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]
2017-05-21 ModuleBv2 is ready for the printers.
    [moduleB_top_v2.scad, moduleB_top_v2.stl]
2017-07-13 Organising and adding a new v2 for the code.
    [moduleA-backplate.scad, moduleA-backplate.stl, moduleA-build.scad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]
2017-07-14 Working ModuleA for the Arduino Micro. Woop!
2017-07-15 V2 of the breadboard. Wire it like this.
    [ModuleA.fzz, ModuleA_v2.fzz]
2017-07-19 Add spacer to A. A wall, basically.
    [ModuleA_Spacer.scad, ModuleA_Spacer.stl, ModuleA_v2.fzz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]
2017-07-22 Add arduino Micro holder, a bottom plate, and an STL file with everything put together. That one should not be printed. Also updates to teh frizing file.
    [ModuleA_Spacer.scad, ModuleA_Spacer.stl, ModuleA_v2.fzz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]
2017-07-22 Remove merge info.
    [ModuleA_Spacer.scad]
2017-07-22 Add STL of whole moduleA. DO NOT PRINT THIS! ONLY FOR SHOW!
    [mA.stl]
2017-07-22 Turn the holder the other way. No reason to have it upside down. Also add screw holes so you can hold it securely in place.
    [mA.scad, moduleA_Bottom.scad, moduleA_Bottom.stl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]
2017-08-20 Switched places on A:s Alt. Rotate a key on B.
    [moduleB-wireframe.scad, moduleB-wireframe.stl, moduleB_top_v2.scad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]
2017-08-20 Better design of the whole module, I think...
    [moduleB_top_v2_Complete.scad, moduleB_top_v2_Complete.stl]
2017-10-06 Module B breadboard layout. Uses the same pins as A, which is nice.
    [ModuleB.fzz]
2017-10-06 Start work on how the layerd code should be (not done), also add the printing design for ModuleB. Since the bottom is the same as ModA, only the top layer is what differs between them. Might put them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
    [moduleB_top_v2_Complete.scad, moduleB_top_v2_Complete_top+spacer+uSupport.stl, moduleB_top_v2_holder+bottom.stl]
2017-10-30 Layers work. No work on media keys though. They seem to be a bit tricky. Need to assign a new controller for them, in software, like they have their own ID and stuff. Need to investigate how to do it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
    [moduleB_top_v2_Complete.scad]
2017-12-11 Add print screen key
2019-04-07 Add KiCAD files
    Would be fun to actually make a PCB for the keyboard instead of
    handwireing. Taking a stab at using KiCAD for the desing. Seems to be a
    program that fits my needs. PCB design can be finickey I noticed...
    [ModuleB-B_Cu.gbl, ModuleB-B_Mask.gbs, ModuleB-B_Paste.gbp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]

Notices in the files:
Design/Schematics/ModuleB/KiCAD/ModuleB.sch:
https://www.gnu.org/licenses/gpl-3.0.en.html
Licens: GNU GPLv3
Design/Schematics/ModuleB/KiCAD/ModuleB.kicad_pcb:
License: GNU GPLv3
